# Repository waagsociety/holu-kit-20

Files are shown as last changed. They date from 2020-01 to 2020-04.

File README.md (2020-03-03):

# holu-kit-20
Hollandse Luchten sensor kit, version 2.0.

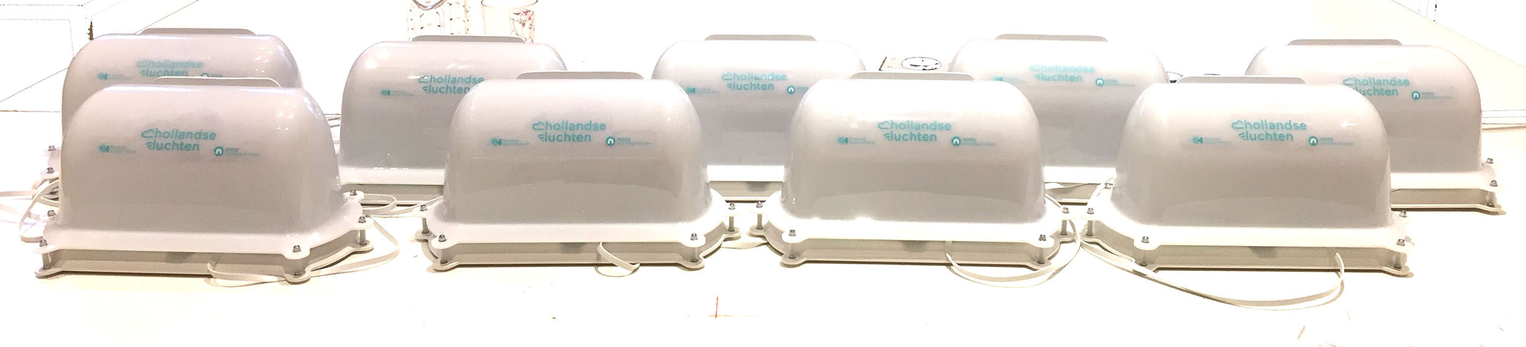
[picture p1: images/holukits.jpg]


This repo has the scope to host the source files of the HoLu kit v2.
In the repo there are:
- sketches for basic and extended HoLu kit
- 3D model of the case
- pcb files and images
- BOM

Some extra information:
- Assembling manual of the HoLu kit: https://hollandseluchten.waag.org/wp-content/uploads/sites/9/HOLU_manual_English.pdf
- Parts descriptions: https://hollandseluchten.waag.org/holu-sensorkit/
- Troubleshooting: https://hollandseluchten.waag.org/veelgestelde-vragen/

In this repo you also find the presentations related to the HoLu kit, the slides have been used during internal meetings and meet-up with the participants of the projects.

Missing:
- ~~3D model of the moulds~~: the 3D models of the moulds were designed by the company that produced the casings, the moulds are based on the original 3D models you find in this repo.
- 2D model internal acrylic plate.

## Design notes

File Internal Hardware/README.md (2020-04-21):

## Hardware - holu-kit-20

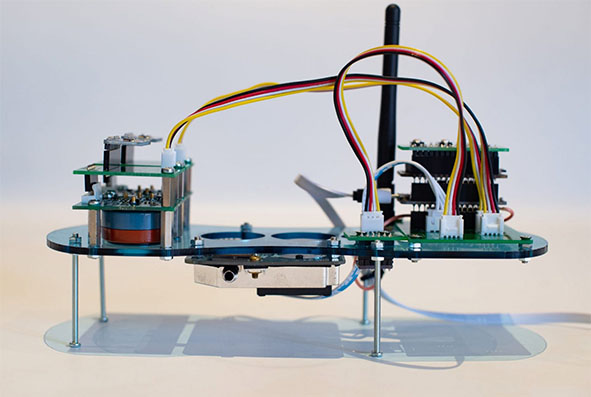
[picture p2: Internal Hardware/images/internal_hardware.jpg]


Hollandse Luchten sensor kit, version 2.0.

In this folder you find the digital files for the pcbs production used to connect the different modules of the HoLu kit v2.

The Eagle files are the design files of the printed circuit boards. The basic HoLu kit includes:
- HL_sensors_pcb_all (schematic and layout)
- HL_Interface_pcb (schematic and layout)
- hl_bme280_out_pcb (schematic and layout)

The extended HoLu kit has all the modules mentioned above and also the following ones:
- HL_gas_no2_pcb (schematic and layout)
- HL_gas_o3_pcb (schematic and layout)

The Gerber files were submitted to the out-sourced service that produced the 200 HoLu kits boards.
The boards were produced by https://jlcpcb.com/.

The images below show the boards and the components that populate them. The components specifications can be found in the BOM

## Sensors pcb top view
### Basic

| pcbs  | component locations | populated pcb |
| --- | --- | ---|
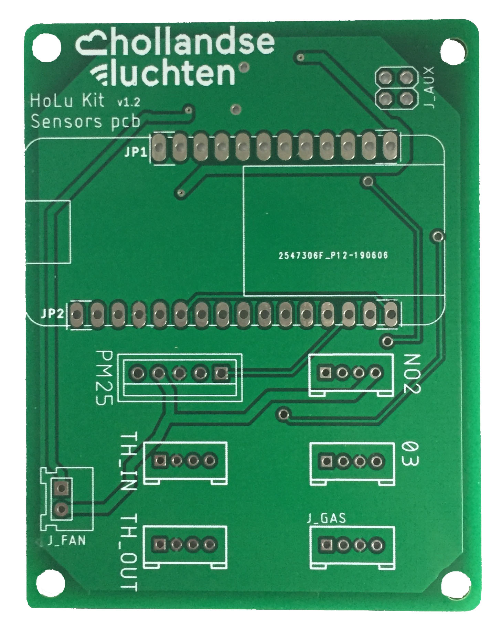
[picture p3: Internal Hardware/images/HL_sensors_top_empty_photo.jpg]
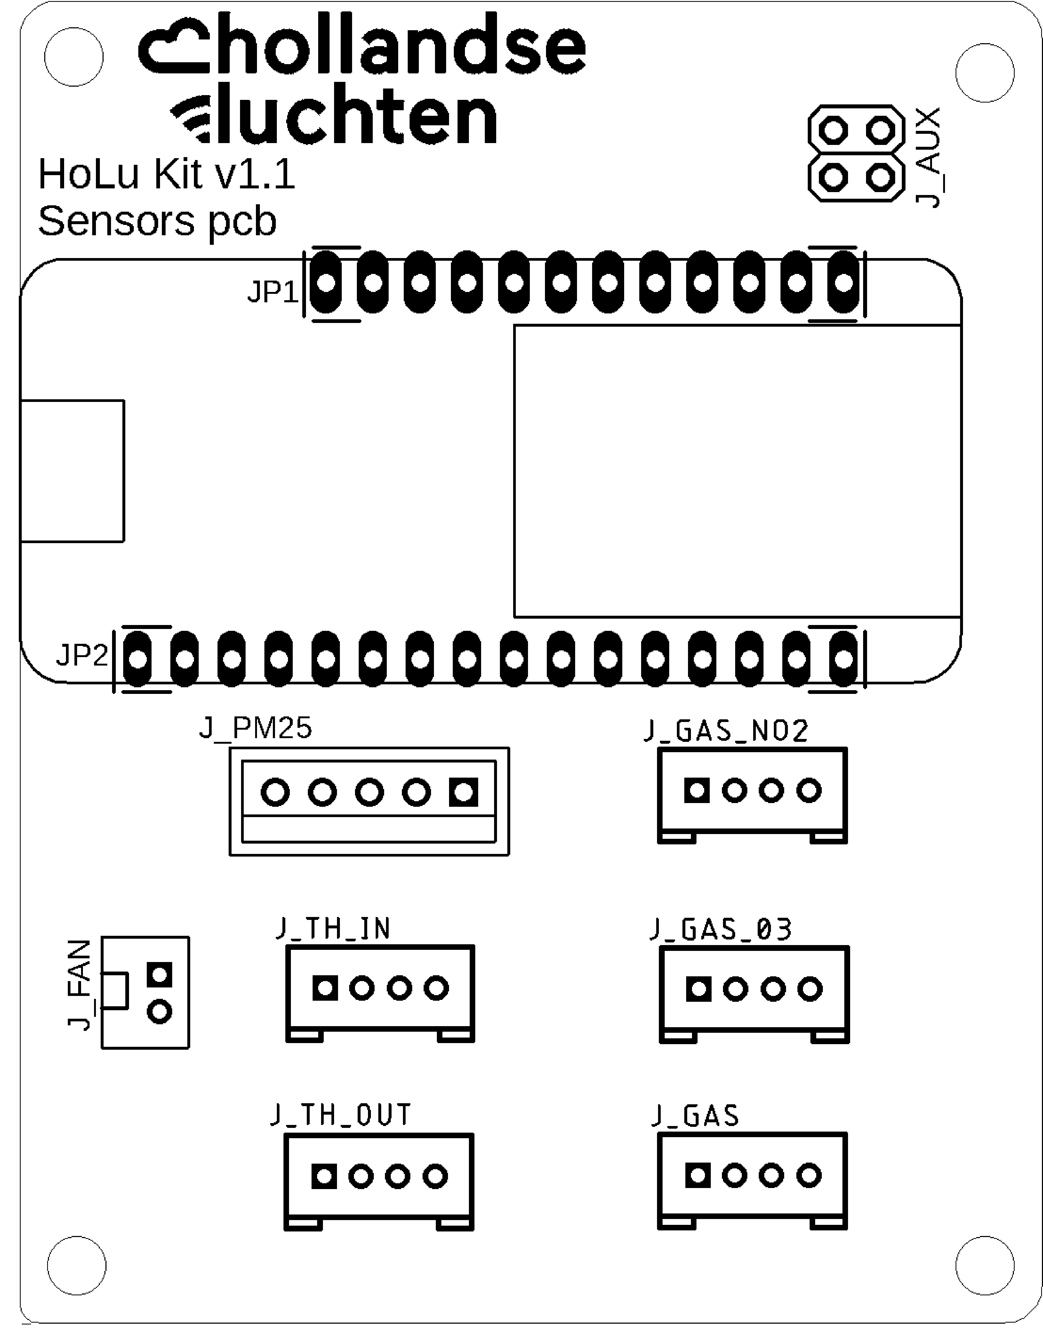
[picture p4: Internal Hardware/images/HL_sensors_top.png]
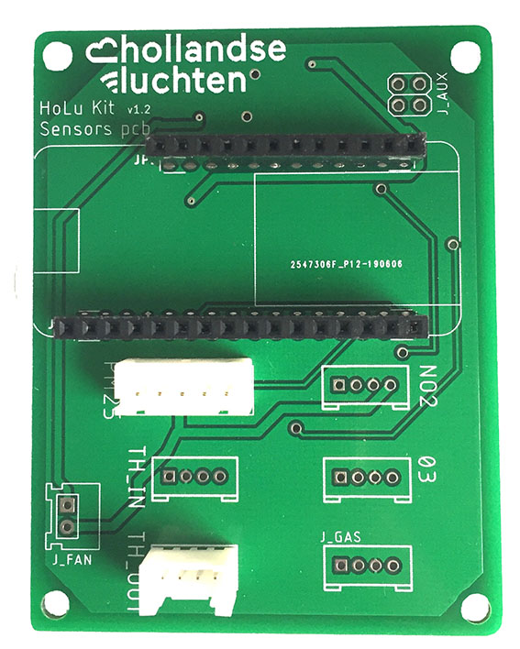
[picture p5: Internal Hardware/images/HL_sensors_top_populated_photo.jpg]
|  |  |  |

Components:
- JP1
- JP2
- J_PM25
- J_TH_IN

### Extended

| pcbs  | component locations | populated pcb |
| --- | --- | ---|
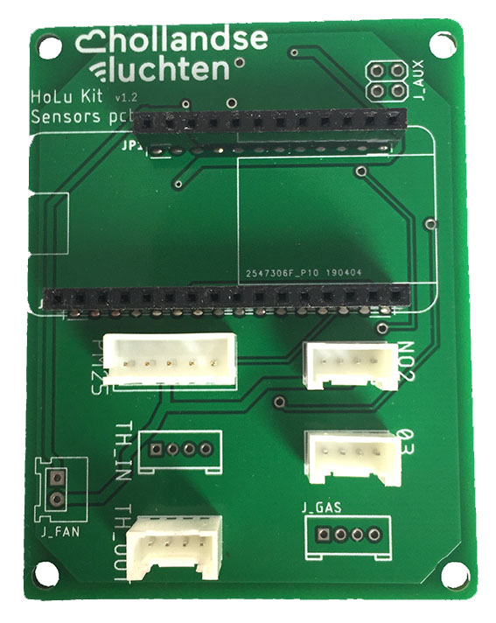
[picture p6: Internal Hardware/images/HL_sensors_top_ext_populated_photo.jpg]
|  |  |  |

Components:
- JP1
- JP2
- J_PM25
- J_TH_IN
- J_GAS_NO2
- J_GAS_O3

## Sensors pcb bottom view
### Basic

| pcbs  | component locations | populated pcb |
| --- | --- | ---|
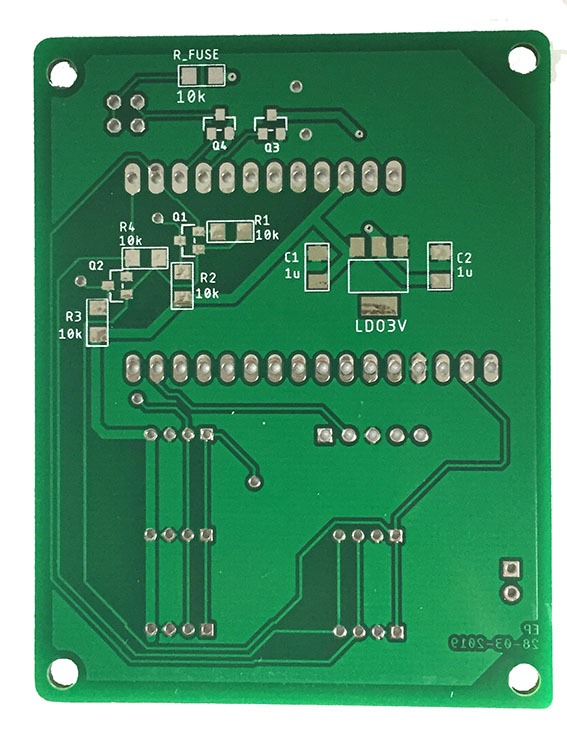
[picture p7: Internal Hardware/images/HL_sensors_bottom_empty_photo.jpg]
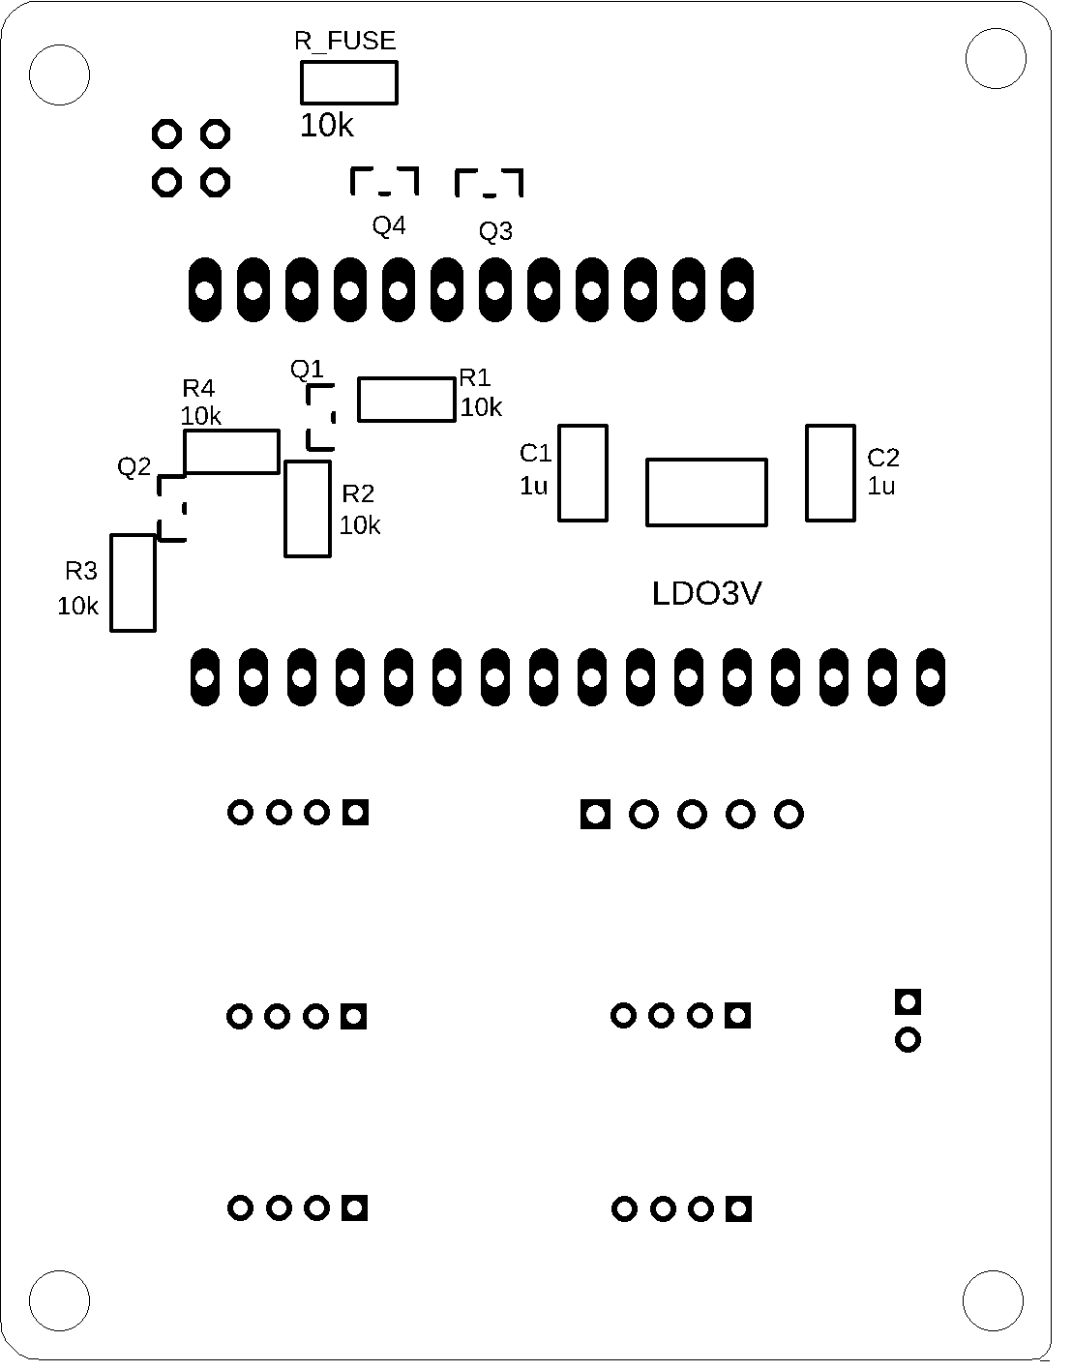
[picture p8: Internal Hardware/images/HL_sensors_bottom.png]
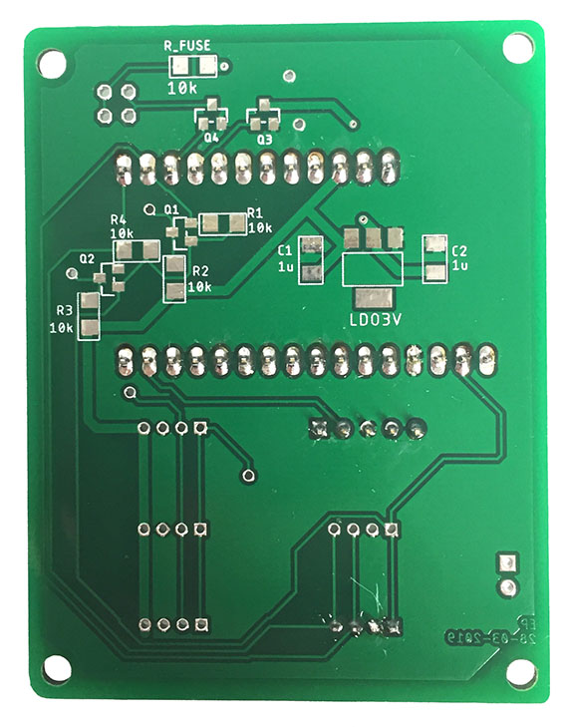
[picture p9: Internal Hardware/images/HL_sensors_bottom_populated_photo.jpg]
|  |  |  |

### Extended

| pcbs  | component locations | populated pcb |
| --- | --- | ---|
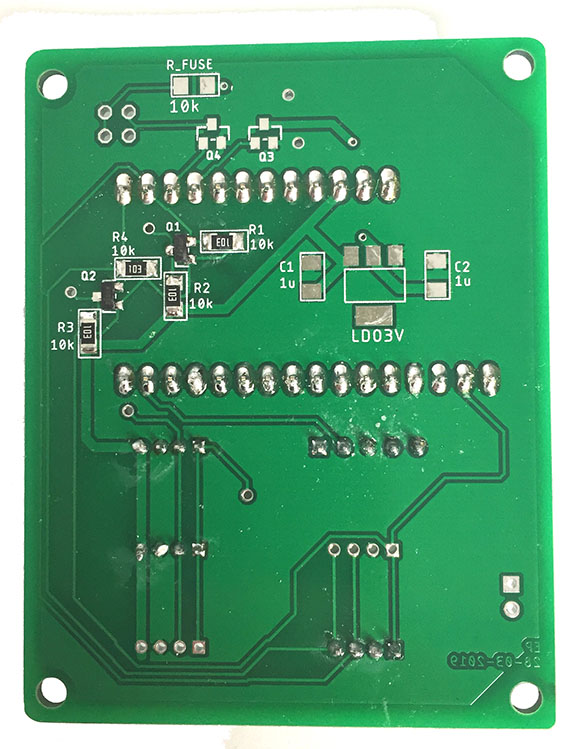
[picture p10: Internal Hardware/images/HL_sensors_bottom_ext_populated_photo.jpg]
|  |  |  |

Components:
- Q1, Q2
- R1, R2, R3, R4

### Interface pcb top view
## Basic and Extended

| pcbs  | component locations | populated pcb |
| --- | --- | ---|
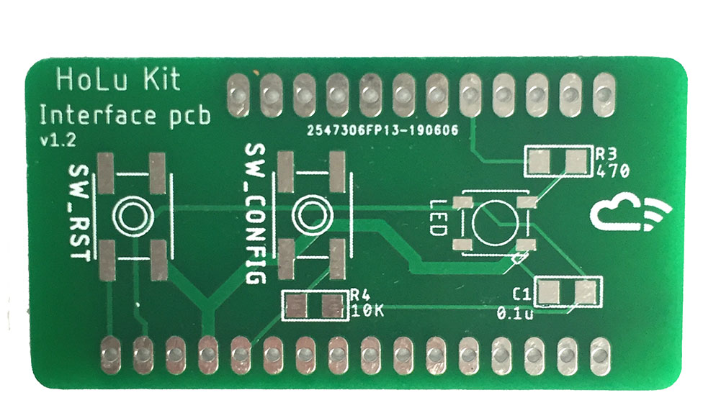
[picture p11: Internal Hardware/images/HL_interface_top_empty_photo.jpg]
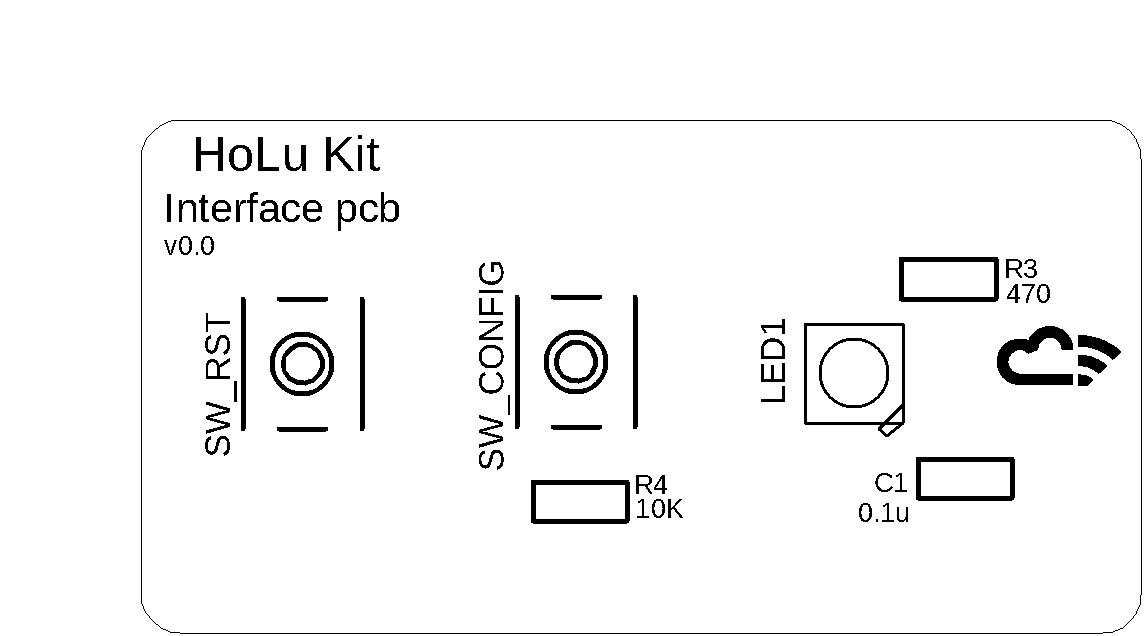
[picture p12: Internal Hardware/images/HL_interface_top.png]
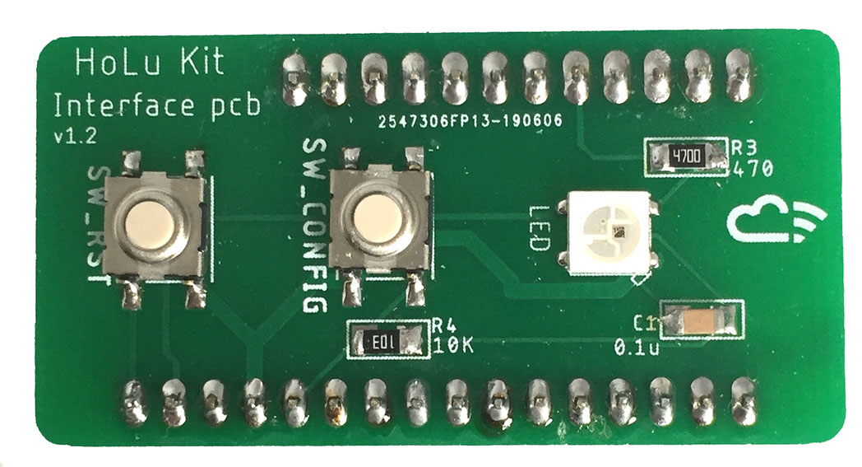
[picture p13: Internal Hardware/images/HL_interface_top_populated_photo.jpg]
|  |  |  |

Components:
- SW_RST
- SW_CONFIG
- R3, R4
- C1
- LED1

## Interface pcb bottom view
### Basic and Extended

| pcbs  | component locations | populated pcb |
| --- | --- | ---|
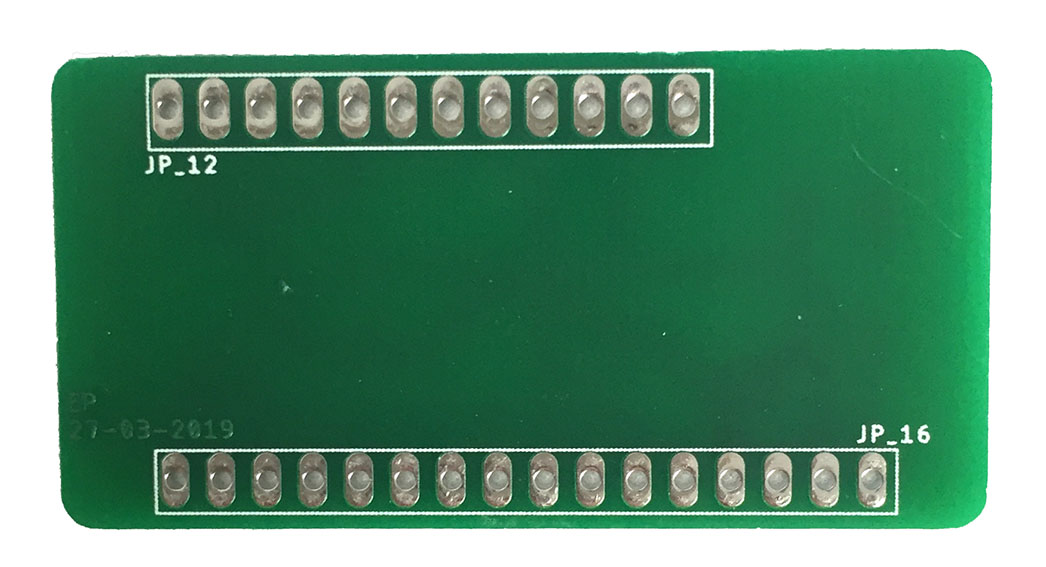
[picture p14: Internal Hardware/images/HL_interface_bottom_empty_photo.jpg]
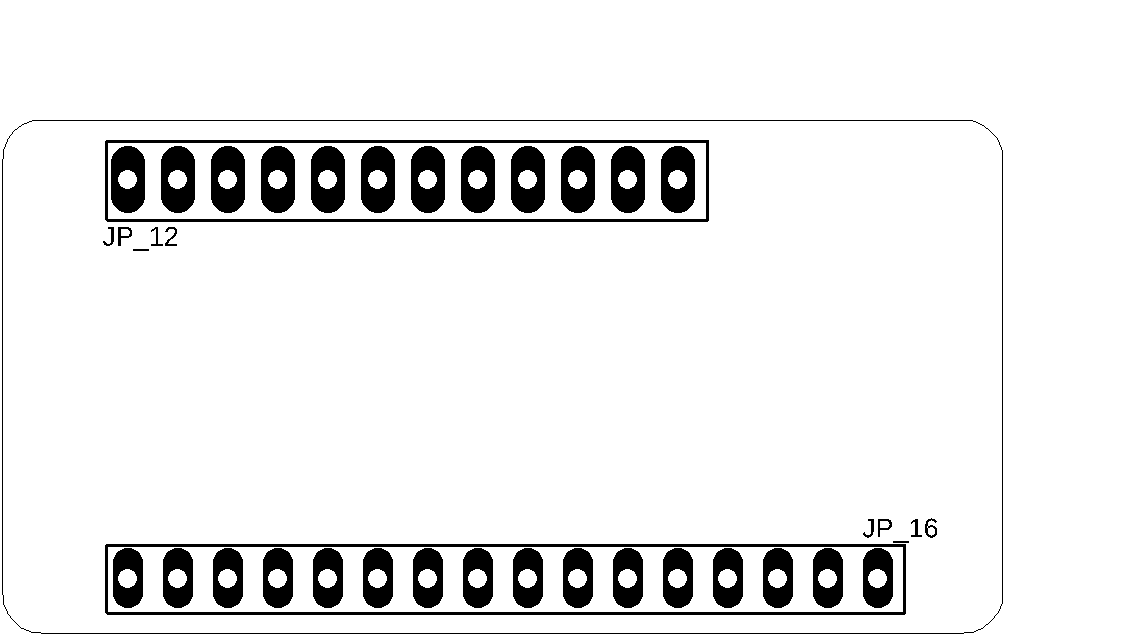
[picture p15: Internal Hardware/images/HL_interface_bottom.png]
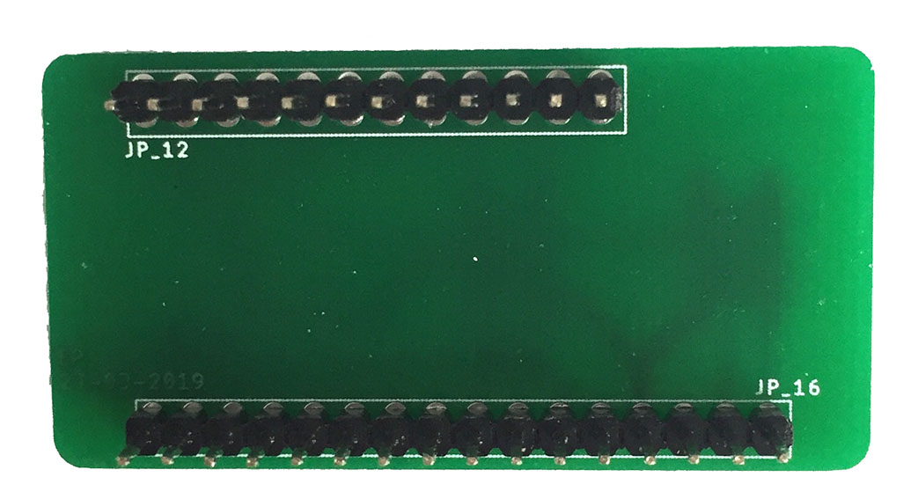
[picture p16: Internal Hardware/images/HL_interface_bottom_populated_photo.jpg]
|  |  |  |

Components:
- JP_12
- JP_16

## BME pcb top view
### Basic and Extended

| pcbs  | component locations | populated pcb |
| --- | --- | ---|
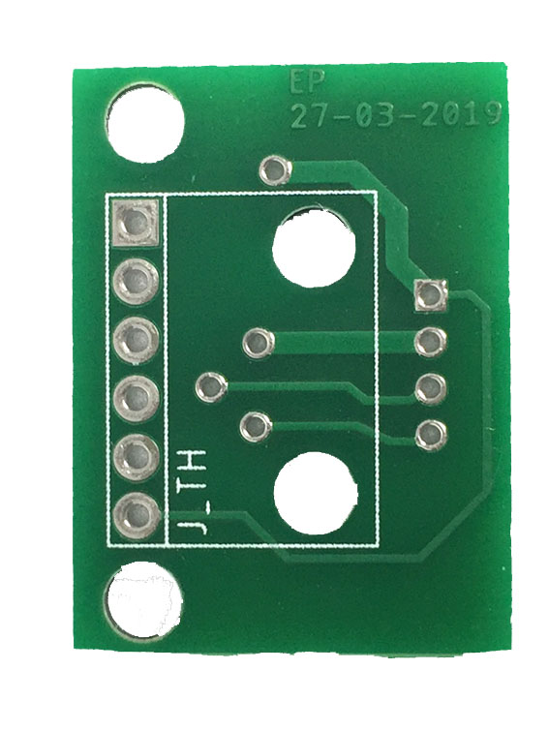
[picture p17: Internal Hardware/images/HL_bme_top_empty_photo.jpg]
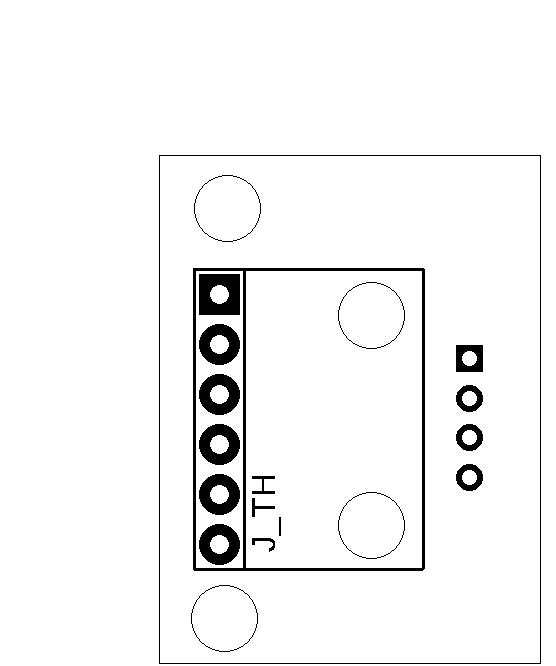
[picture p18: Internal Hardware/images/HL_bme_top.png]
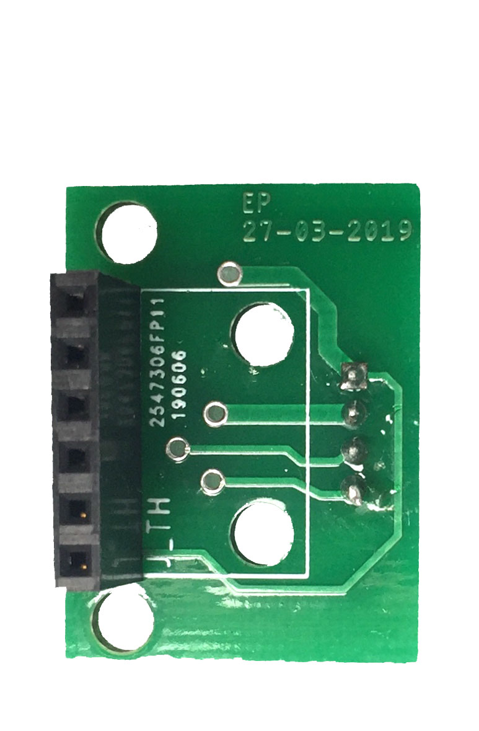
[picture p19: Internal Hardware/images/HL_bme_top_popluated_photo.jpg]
|  |  |  |

Components:
- J_TH

## BME pcb bottom view
### Basic and Extended

| pcbs  | component locations | populated pcb |
| --- | --- | ---|
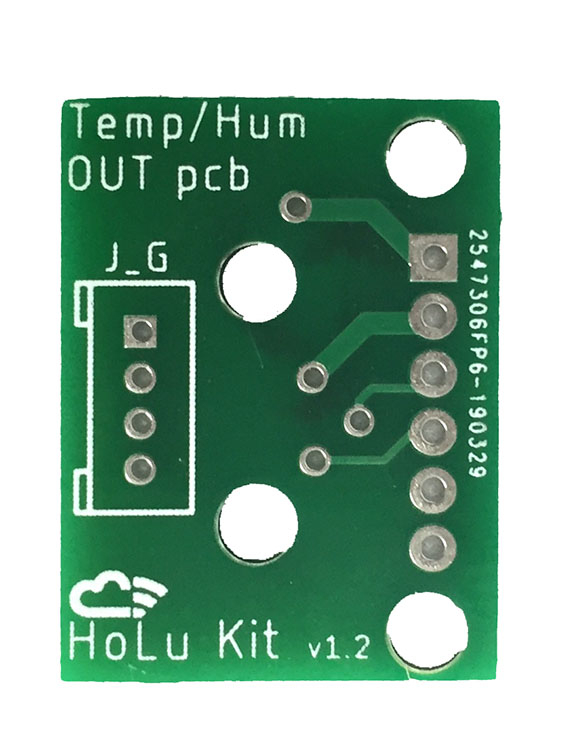
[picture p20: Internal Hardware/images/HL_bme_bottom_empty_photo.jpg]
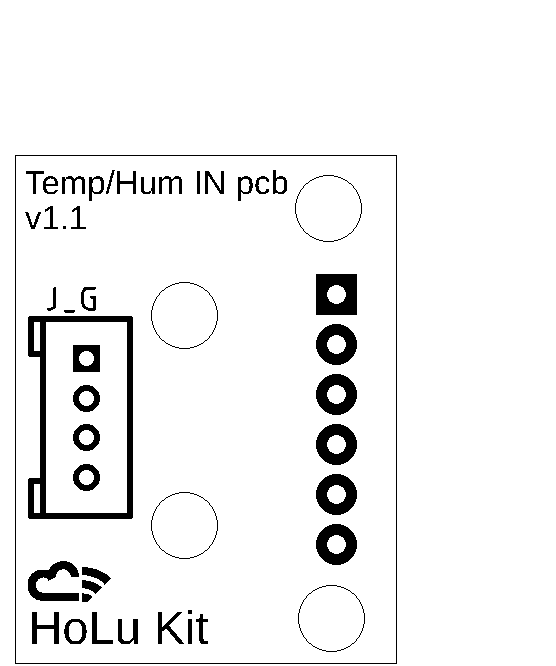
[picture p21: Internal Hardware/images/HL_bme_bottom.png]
|  |  |  |

Components:
- J_G

## GAS pcbs top view
### Extended

| pcbs  | component locations | populated pcb |
| --- | --- | ---|
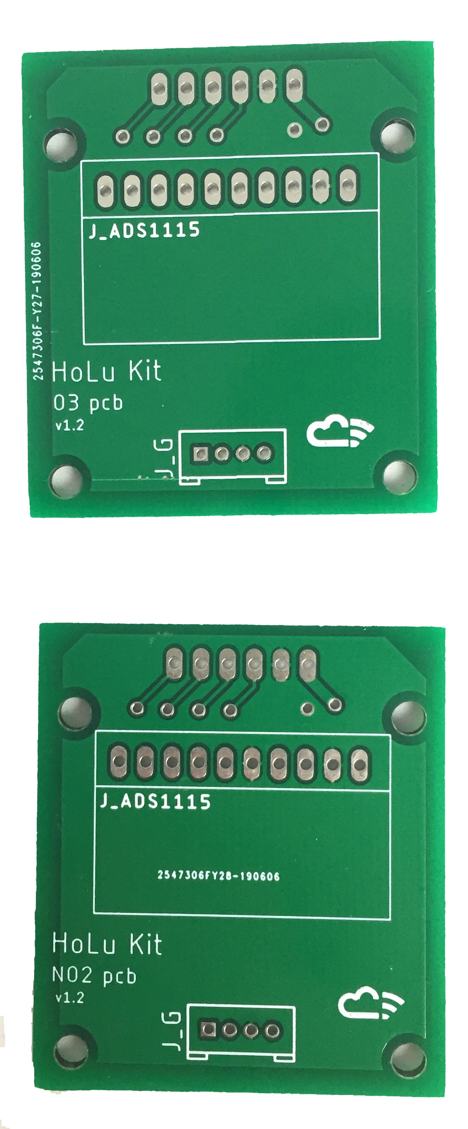
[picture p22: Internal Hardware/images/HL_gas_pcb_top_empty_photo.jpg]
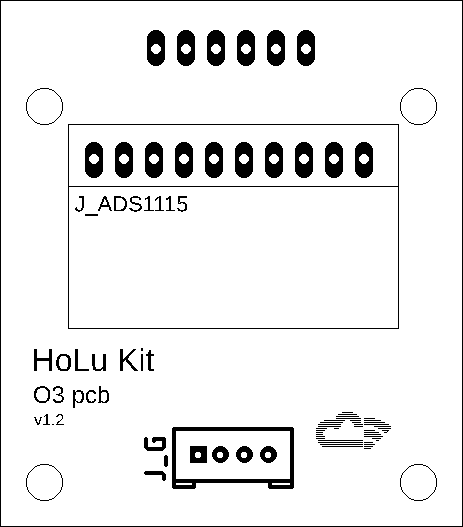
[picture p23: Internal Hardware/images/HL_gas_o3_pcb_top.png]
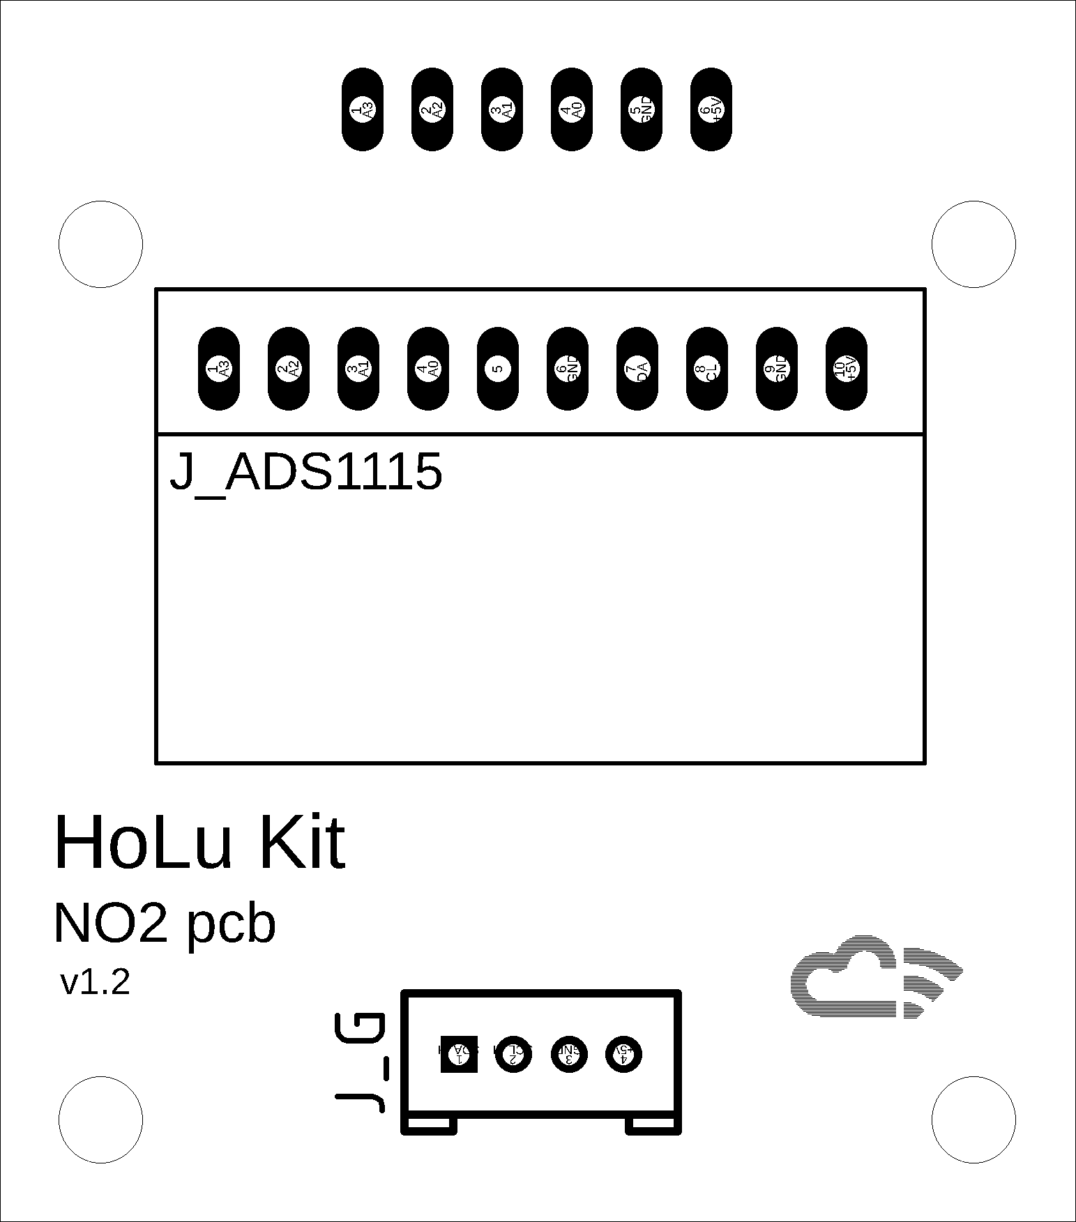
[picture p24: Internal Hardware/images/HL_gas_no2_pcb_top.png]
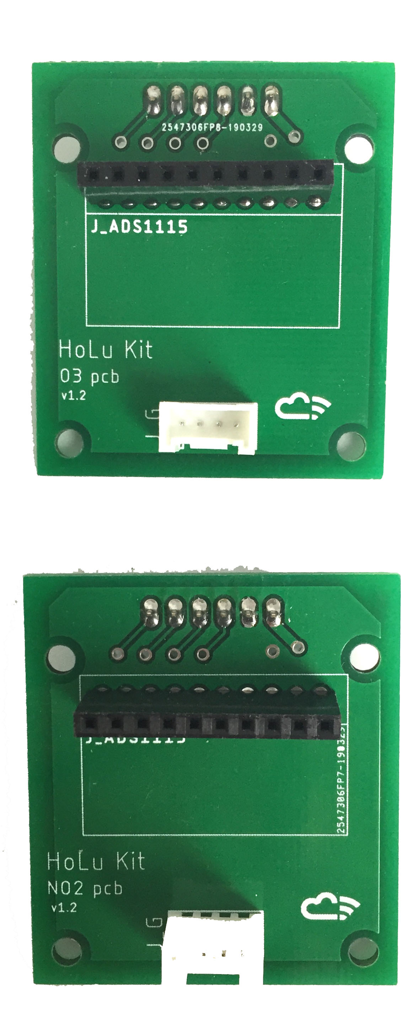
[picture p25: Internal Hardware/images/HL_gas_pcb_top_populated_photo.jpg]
|  |   |  |

Components:
- J_GAS
- J_ADS115

## GAS pcbs bottom view
### Extended

| pcbs  | component locations | populated pcb |
| --- | --- | ---|
|  |    |  |

Components:
- J_O3
- C1, C2

## EXTRA
### Internal plate
The HoLu kit uses an acrylic plate to hold the sensors and the electronic parts in place. The plates were cut in the Fablab at De Waag.


### Feather M0 with RFM95 LORA Radio


It is important to buy the Feather M0 Lora with headers because the connectors that are usually provided attached to the board are too short for this application.
It is necessary to use the long staking headers, see BOM. It is also necessary to solder the coaxial connector for the antenna to the board.
You can find the instruction at this link: https://learn.adafruit.com/adafruit-feather-m0-radio-with-rfm69-packet-radio/antenna-options.

### Adalogger Feather


On this module it is necessary to solder the female connector and insert the battery and the SD-card, https://learn.adafruit.com/adafruit-adalogger-featherwing.

### Temperature and Humidity Sensor
The sesnor selected to measure temperature and humidity is the sensor BME280 from Bosh: https://www.bosch-sensortec.com/products/environmental-sensors/humidity-sensors-bme280/.

Due to tools limitation, the sensor has been deployed on a low cost breakout board:


**NOTE**: During the on the field deployment of the HoLu kits, we observed that temperature sensor BME280 module is too fragile for such application and after a while many it tends to break. The Extended HoLu kit requires the temp/hum sensor for the calibration of the gas sensors so we adopted a different breakout board with the same sensor, the module provided by Adafruit, https://www.adafruit.com/product/2652.


To better protect the module inside the HoLu kit enclosure, it has been located in a more central place inside the casing.



If you are interested on the connection between the extra module, please open an issue in the issue section.

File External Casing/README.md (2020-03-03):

In this section of the repo you find the 3D models, .STEP files, of the HoLu kit casing. It is composed by two parts, the top and the bottom.
The first prototype was designed and made in the Fablab at De Waag.

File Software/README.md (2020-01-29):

# Software
In this folder you find the code used in the basic and extended HoLu kit version 2.

The sketches are written for the Adafruit M0 lora board.<br>
The code for the basic kit is called: HL_main_basic.<br>
The code for the basic kit is called: HL_main_extended.

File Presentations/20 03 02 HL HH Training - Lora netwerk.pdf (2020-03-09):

Hollandse Luchten

Lora netwerk en data infrastructuur

Denis Costa, projectmanager

## Agenda

- Wat is Lora netwerk?
- Waarom Lora netwerk?
- Lora en Hollandse Luchten

## Netwerk

criteria/type netwerk | Accessible for users & dataplatform | Open source | Price | Scalability (200 sensors)
4G | yes | no | expensive | no
Wifi | no | no | free | yes
Lora | yes | yes | free | yes

## Long-RAnge Wide Area Network


https://www.thethingsnetwork.org/


## Overzicht Gateways in de IJmond


https://ttnmapper.org/

## Hollandse Luchten technische infrastructuur

hardware | netwerk- infrastructuur

datainfrastructuur

visualisatie

HoLu-Sensorkits

LoRa Gateways TTN | TTN server
| MQTT broker

WAAG server

RIVM server
kalibratie/correctie

MQTT subscription

MQTT subscription

gekalibreerde/
gecorrigeerde data

kaart op website
Hollandse Luchten
ruwe data

GGD server

http POST

TEOM +
Station Bosweg

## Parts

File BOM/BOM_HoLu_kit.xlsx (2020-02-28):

 | Name | Description | Amount/kit | Supplier | Order code | Minimum Amount | Cost Minimum amount (€) | Cost per Kit (euro) | Link
BASIC |  |  |  |  |  |  | 456.359 | 123.4758
Off the shelf / sensors
 | Feather M0 Lora | FEATHER M0 WITH RFM95 LORA RADIO, Adafruit | 1 | Antratek OR MUISER | P2821 | 1.00 | 39.87 | 39.87 | https://www.antratek.nl/feather-m0-with-rfm95
 | Antenna adapter | SMA naar uFL/u.FL/IPX/IPEX RF kabel | 1 | opencircuit |  | 1 | 5.95 | 5.95 | https://opencircuit.nl/Product/13952/SMA-naar-uFLu.FLIPXIPEX-RF-kabel
 | Atenna connector | RF / Coaxial Connector, U.FL Coaxial, Straight Jack, Solder, 50 ohm, Phosphor Bronze | 1 | farnell |  | 10 | 9.46 | 0.946 | https://nl.farnell.com/hirose-hrs/u-fl-r-smt-01/rf-coaxial-u-fl-straight-jack/dp/3908021
 | Antenna | 868 MHz antenne SMA knik | 1 | Ideetron |  | 1.00 | 5.39 | 5.39 | https://webshop.ideetron.nl/Webwinkel-Product-24476807/868-MHz-antenne-SMA-knik.html
 | Adalogger Feather | Adalogger FeatherWing - RTC + SD Add-on For All Feather Boards | 1 | Open Circuit | ADA-2922 | 1.00 | 7.82 | 7.82 | https://nl.mouser.com/ProductDetail/Adafruit/2922 | https://www.reichelt.nl/experimenteerbord-adalogger-featherwing-rtc-sd-extensie-debo-feather-rtc-p235464.html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 | https://www.hobbyelectronica.nl/product/adalogger-featherwing-rtc-sd/ | https://www.kiwi-electronics.nl/adalogger-featherwing-rtc-sd-add-on | https://www.elektor.nl/adalogger-featherwing-rtc-sd-add-on
 | Feather Stacking Headers | 12-pin and 16-pin female headers | 2 | Open Circuit | ADA-2830 | 1.00 | 1.90 | 3.8 | https://opencircuit.nl/Product/12816/Feather-Stacking-Headers-12-pin-and-16-pin-female-headers
 | BME280 breakout board | BMP280 I2C or SPI Barometric Pressure / Temperature / Altitude Sensor | 1 | tinytronics | 1511 | 1.00 | 4.50 | 4.5 | https://www.tinytronics.nl/shop/nl/sensoren/temperatuur-lucht-vochtigheid/bme280-digitale-barometer-druk-en-vochtigheid-sensor-module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
 | SDS011 | PM2.5 sensor | 1 | tiny tronics | 1548 | 1.00 | 25.00 | 25 | https://www.tinytronics.nl/shop/nl/sensoren/temperatuur-lucht-vochtigheid/nova-sds011-hoge-precisie-laser-stofsensor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
Interface pcb
 | JP3 | Board-To-Board Connector, Vertical, 2.54 mm, 12 Contacts, Through Hole, 1 Rows | 1 |  |  |  |  |  | use from other components, no need to buy it
 | JP1 | Board-To-Board Connector, 2.54 mm, 16 Contacts, Receptacle, WR-PHD Series, Through Hole, 1 Rows | 1 |  |  |  |  |  | use from other components, no need to buy it
 | SW_RST, SW_CONFIG | Tactile Switch, B3SN Series, Top Actuated, SMD, Round Button, 160 gf, 50mA at 24VDC | 2 | Farnell | 2076274 | 5 | 3.75 | 1.5 | https://nl.farnell.com/omron-electronic-components/b3sn-3112p/switch-6x6x3-1mm-sealed-1-57n/dp/2076274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
 | R1 | RC1206JR-0710KL - SMD Chip Resistor, 1206 [3216 Metric], 10 kohm, RC Series, 200 V, Thick Film, 250 mW | 1 | farnell | 9240640 | 10.00 | 0.61 | 0.061 | https://nl.farnell.com/yageo/rc1206jr-0710kl/res-10k-5-0-25w-1206-thick-film/dp/9240640
 | R2 | RC1206FR-07470RL - SMD Chip Resistor, 1206 [3216 Metric], 470 ohm, RC Series, 200 V, Thick Film, 250 mW | 1 | farnell | 9240926 | 10.00 | 0.70 | 0.0699 | https://nl.farnell.com/yageo/rc1206fr-07470rl/res-470r-1-0-25w-1206-thick-film/dp/9240926
 | C1 | C1206C104KARACTU - SMD Multilayer Ceramic Capacitor, Tip & Ring, 0.1 µF, 250 V, 1206 [3216 Metric], ± 10%, X7R | 1 | farnell | 2429364 | 10.00 | 3.31 | 0.331 | https://nl.farnell.com/kemet/c1206c104karactu/cap-0-1-f-250v-10-x7r-1206/dp/2429364?st=C1206C104KARACTU
 | LED1 | WS2812B RGB Led, Neopixel, package 5050 | 1 | Opencircuit | 10707 | 10.00 | 1.95 | 0.195 | https://opencircuit.nl/Product/10707/WS2812B-RGB-led-10-stuks
Temp/Hum pcb (2 boards)
 | J3 | 61300611821 - Board-To-Board Connector, 2.54 mm, 6 Contacts, Receptacle, WR-PHD Series, Through Hole, 1 Rows | 1 | farnell | 1109731 | 10.00 | 2.04 | 0.204 | https://nl.farnell.com/wurth-elektronik/61300611821/connector-rcpt-6pos-1row-2-54mm/dp/2827893
 | J1 | Grove - Universal 4-Pin Connector | 1 | Kiwi electronics | SS-110990030 | 10.00 | 1.31 | 0.131 | https://nl.mouser.com/ProductDetail/Seeed-Studio/110990030
Sensor pcb basic
 | JP2 | Board-To-Board Connector, 2.54 mm, 16 Contacts, Receptacle, WR-PHD Series, Through Hole, 1 Rows | 1 | Farnell | 2827905 | 10.00 | 5.64 | 0.564 | https://nl.farnell.com/wurth-elektronik/61301611821/connector-rcpt-16pos-1row-2-54mm/dp/2827905
 | JP1 | Board-To-Board Connector, 2.54 mm, 12 Contacts, Receptacle, WR-PHD Series, Through Hole, 1 Rows | 1 | Farnell | 2827901 | 10.00 | 4.90 | 0.49 | https://nl.farnell.com/wurth-elektronik/61301211821/connector-rcpt-12pos-1row-2-54mm/dp/2827901
 | J-TH (x2) | Grove - Universal 4-Pin Connector | 2 | Kiwi electronics | SS-110990030 | 10.00 | 1.31 | 0.262 | https://www.kiwi-electronics.nl/grove-universal-4-pin-connector-10-pack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
 | 05-JST-B5B | Dust - Wire-To-Board Connector, Vertical, 2.5 mm, 5 Contacts, Header, XH Series, Through Hole, 1 Rows | 1 | farnell | 1516281 | 100.00 | 14.60 | 0.146 | https://nl.farnell.com/jst-japan-solderless-terminals/b5b-xh-a-lf-sn/header-tht-vertical-2-5mm-5way/dp/1516281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
Extra
 | grove cables | Grove - Universal 4 Pin Unbuckled 20cm Cable. | 1 | mouser.nl |  | 5.00 | 2.53 | 0.506 | https://nl.mouser.com/ProductDetail/Seeed-Studio/110990031
 | usb cable | Micro USB kabel - 1.8m | 1 | tinytronics |  | 1.00 | 2.50 | 2.5 | https://www.tinytronics.nl/shop/en/cables/usb/micro-usb-cable-1.8m
 | usb adapter/charger | USB wall adapter | 1 | tinytronics |  | 1 | 6.5 | 6.5 | https://www.tinytronics.nl/shop/en/power-supplies/5v/goobay-44951-dual-usb-power-supply-5v-2.4a-black
 | sdscard | opencircuit | 1 | open circuit |  | 1 | 6.95 | 6.95 | https://opencircuit.nl/Product/11234/8GB-Micro-SD-geheugenkaart
 | battery for RTC | CR1220 3V lithium metal coin cell battery | 1 | allekabels |  | 5 | 1.99 | 0.398 | https://www.allekabels.nl/knoopcel-batterij/1067/1296899/knoopcel-batterij.html
 | metal rings |  | 2
 | rip-tie |  | 1 | local shop |  | 100 | 4 | 0.08
 | metal plate with screws |  | 1
Fasteners (internal)
 | M3 nut | Jeveca | 9 | Jeveka |  | 1000 | 25.9 | 0.2331 | https://www.jeveka.com/nl/catalog/metrische-zeskant-en-vierkantmoeren/lage-zeskantmoeren/lage-zeskantmoeren-4390006z/4390006z0030000/staal-klasse-4-4.6-4.8/m-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
 | borgringen | essentracomponents | 9 | Jeveka |  | 1000 | 24 | 0.216 | https://www.essentracomponents.com/nl-nl/p/borgringen/015103000203
 | M3x12 bolt | Jeveca | 9 | Jeveka |  | 2000 | 53.2 | 0.2394 | https://www.jeveka.com/nl/catalog/metrische-metaalschroeven-met-torx-of-kruisgleuf/bolcilinderschroeven-met-kruisgleuf-staal/bolcilinderschr.kr.gl.h-7985004z/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
Fasteners to acrilic/bottom
 | M3x50 bolt | Jeveca | 4 | Jeveka |  | 200 | 38.6 | 0.772 | https://www.jeveka.com/nl/catalog/metrische-metaalschroeven-met-torx-of-kruisgleuf/bolcilinderschroeven-met-kruisgleuf-staal/bolcilinderschr.kr.gl.h-7985004z/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
 | M3 nut | Jeveca | 8 | Jeveka |  | 1000 | 25.9 | 0.2072 | https://www.jeveka.com/nl/catalog/metrische-zeskant-en-vierkantmoeren/lage-zeskantmoeren/lage-zeskantmoeren-4390006z/4390006z0030000/staal-klasse-4-4.6-4.8/m-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
 | M3 washer | Jeveca | 16 | Jeveka |  | 5000 | 15 | 0.048 | https://www.jeveka.com/nl/catalog/sluitringen-en-borgplaten/sluitringen-vlak-normaal-staal-zn-tzn-zndikgepass-zinklamel/sluitringen-normaal-voor-6-kt-125a001z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
 | M3x16mm plastic spacer | Mouser | 8 | Mouser |  | 1 | 0.49 | 3.92 | https://nl.mouser.com/ProductDetail/855-R30-6701694
Fasteners top/bottom
 | M3x30 bolt | Jeveka | 6 | Jeveka |  | 1000 | 50 | 0.3 | https://www.jeveka.com/nl/catalog/metrische-metaalschroeven-met-torx-of-kruisgleuf/bolcilinderschroeven-met-kruisgleuf-staal/bolcilinderschr.kr.gl.h-7985004z/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
 | M3x16mm plastic spacer | Mouser | 6 | Mouser |  | 1 | 0.49 | 2.94 | https://nl.mouser.com/ProductDetail/855-R30-6701694
 | M3 washer | Jeveka | 24 | Jeveka |  | 5000 | 15 | 0.072 | https://www.jeveka.com/nl/catalog/sluitringen-en-borgplaten/sluitringen-vlak-normaal-staal-zn-tzn-zndikgepass-zinklamel/sluitringen-normaal-voor-6-kt-125a001z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
 | M3 nut | Jeveka | 6 | Jeveka |  | 1000 | 25.9 | 0.1554 | https://www.jeveka.com/nl/catalog/metrische-zeskant-en-vierkantmoeren/lage-zeskantmoeren/lage-zeskantmoeren-4390006z/4390006z0030000/staal-klasse-4-4.6-4.8/m-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
 | M3 self-locking Nut | Javeka | 6 | Jeveka |  | 500 | 17.4 | 0.2088 | https://www.jeveka.com/nl/catalog/metrische-moeren-zelfborgend-durlok-en-andere-vormen/zelfborgende-moeren-staal-met-kunststof-ring/zelfb.zesk.moeren-kunstst.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
Extra not counted
 | acrilic plate | 3mm, 20x30cm | 1 | kunststofplatenshop |  |  |  |  |  | b. Solderen elektronische boards 1 uur per stuk * 10 sensoren = 10 uur |  |  |  | 10
EXTRA COMPONENTS FOR EXTENDED |  |  |  |  |  |  | 115.785 | 112.8336
Off the shelf / sensors
 | NO2-B43F | NO2 sensor Compact, 4-electrode, low ppb | 1 | alphasense |  |  |  |  | http://www.alphasense.com/
 | OX-B431 | O3 Compact, 4-electrode, low ppb | 1 | alphasense |  |  |  |  | http://www.alphasense.com/
 | ISB Individual Sensor Board | ISB for B series 4-electrode sensors | 2 | alphasense |  |  |  |  | http://www.alphasense.com/
 | ADS1115 | ADC converter | 2 | opencircuit |  | 1.00 | 15.25 | 30.5 | https://opencircuit.nl/Product/14001/ADS1115-16-Bit-ADC-4-kanaals-met-Programmeerbare-gain-versterker
Sensor pcb basic
 | J-TH (x2) | Grove - Universal 4-Pin Connector | 2 | Kiwi electronics | SS-110990030 | 10.00 | 1.31 | 0.262 | https://www.kiwi-electronics.nl/grove-universal-4-pin-connector-10-pack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
 | Q1 Q2 | MOSFET Transistor, N Channel, 1.7 A, 30 V, 0.065 ohm, 10 V, 1.6 V | 2 | farnell | 9845429 | 5.00 | 1.68 | 0.67 | https://nl.farnell.com/on-semiconductor/nds355an/mosfet-n-sot-23/dp/9845429?st=NDS355AN
 | R1 R2 R3 R4 | RC1206JR-0710KL - SMD Chip Resistor, 1206 [3216 Metric], 10 kohm, RC Series, 200 V, Thick Film, 250 mW | 4 | farnell | 9240640 | 10.00 | 0.61 | 0.244 | https://nl.farnell.com/yageo/rc1206jr-0710kl/res-10k-5-0-25w-1206-thick-film/dp/9240640
Extra
 | grove cables | Grove - Universal 4 Pin Unbuckled 20cm Cable. | 2 | mouser |  | 5.00 | 2.53 | 1.012 | https://nl.mouser.com/ProductDetail/Seeed-Studio/110990031
Gas pcb NO2
 | grove cables | Grove - Universal 4 Pin Unbuckled 20cm Cable. | 1 | mouser |  | 5.00 | 2.53 | 0.506 | https://nl.mouser.com/ProductDetail/Seeed-Studio/110990031
 | JP1 | 2212S-10SG-85 - Board-To-Board Connector, 2.54 mm, 10 Contacts, Receptacle, 2212S Series, Through Hole, 1 Rows | 1 | farnell |  | 5 | 1.125 | 0.225 | https://nl.farnell.com/multicomp/2212s-10sg-85/socket-pcb-1-row-10way/dp/1593464
 | C1 | C1206C104KARACTU - SMD Multilayer Ceramic Capacitor, Tip & Ring, 0.1 µF, 250 V, 1206 [3216 Metric], ± 10%, X7R | 1 | farnell |  | 5 | 1.655 | 0.331 | https://nl.farnell.com/kemet/c1206c104karactu/cap-0-1-f-250v-10-x7r-1206/dp/2429364?st=C1206C104KARACTU
 | C2 | 12065C105JAT2A - SMD Multilayer Ceramic Capacitor, 1 µF, 50 V, 1206 [3216 Metric], ± 5%, X7R, AVX 1206 MLCC | 1 | farnell |  | 5 | 3.01 | 0.602 | https://nl.farnell.com/avx/12065c105jat2a/cap-1-f-50v-5-x7r-1206/dp/1740706
Fasteners (internal)
 | Offset pillar m3x16 m-f |  | 8 | farnell |  | 1 | 7.93 | 63.44 | https://nl.farnell.com/webapp/wcs/stores/servlet/ProductDisplay?scope=partnumberlookahead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
 | Offset pillar m3x13 m-f |  | 4 | farnell |  | 1 | 3.66 | 14.64 | https://nl.farnell.com/harwin/r30-3001302/standoff-hex-brass-13mm-m3/dp/2395872
 | M3x6 bolt |  | 8 | Jeveka |  | 2000 | 48.6 | 0.1944 | https://www.jeveka.com/nl/catalog/metrische-metaalschroeven-met-torx-of-kruisgleuf/bolcilinderschroeven-met-kruisgleuf-staal/bolcilinderschr.kr.gl.h-7985004z/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
 | M3 nut |  | 8 | Jeveka |  | 1000 | 25.9 | 0.2072 | https://www.jeveka.com/nl/catalog/metrische-zeskant-en-vierkantmoeren/lage-zeskantmoeren/lage-zeskantmoeren-4390006z/4390006z0030000/staal-klasse-4-4.6-4.8/m-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

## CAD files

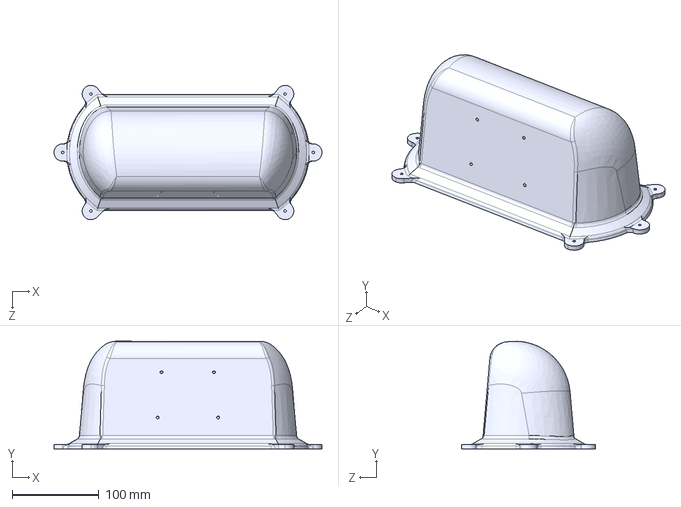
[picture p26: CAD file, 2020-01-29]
External Casing/HoLu kit Top case.STEP
308.4 x 123.7 x 154.6 mm

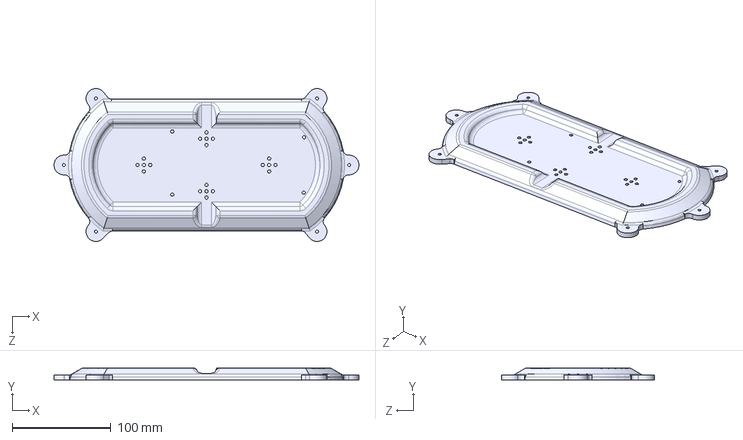
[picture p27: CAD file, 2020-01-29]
External Casing/HoLu kit Bottom case.STEP
308.4 x 12.5 x 154.6 mm

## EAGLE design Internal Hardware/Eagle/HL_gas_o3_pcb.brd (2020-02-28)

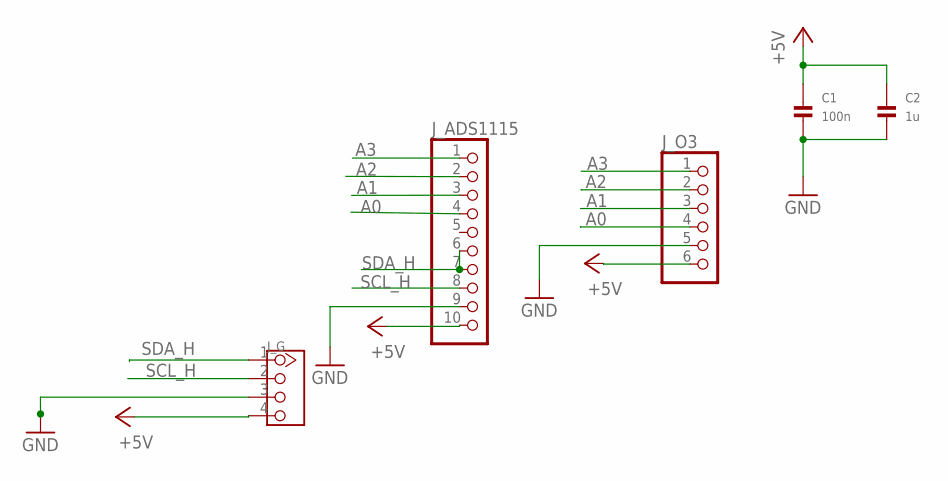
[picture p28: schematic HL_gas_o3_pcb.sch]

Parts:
C1: 100n; 1206
C2: 1u; 1206
J_ADS1115: HEADER-1X10; 1X10_OVAL
J_G: TWIG-4P-2.0-2.0; 4P-2.0
J_O3: HEADER-1X6; 1X06_OVAL

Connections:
+5V: C1.1, C2.1, J_ADS1115.10, J_G.4, J_O3.6
A0: J_ADS1115.4, J_O3.4
A1: J_ADS1115.3, J_O3.3
A2: J_ADS1115.2, J_O3.2
A3: J_ADS1115.1, J_O3.1
GND: C1.2, C2.2, J_ADS1115.9, J_G.3, J_O3.5
SCL_H: J_ADS1115.8, J_G.2
SDA_H: J_ADS1115.6, J_ADS1115.7, J_G.1

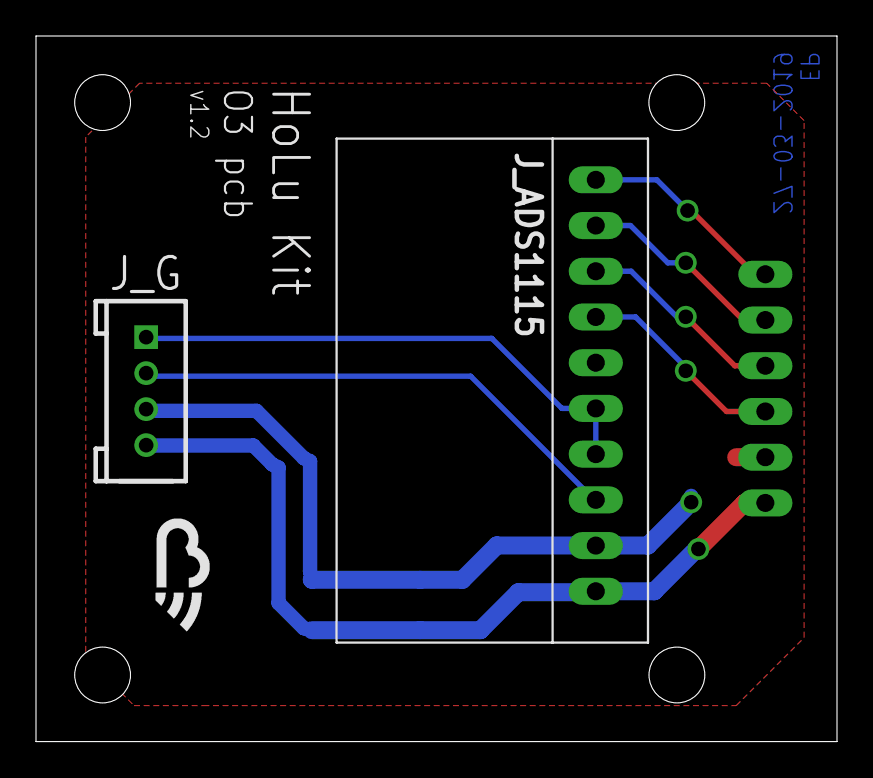
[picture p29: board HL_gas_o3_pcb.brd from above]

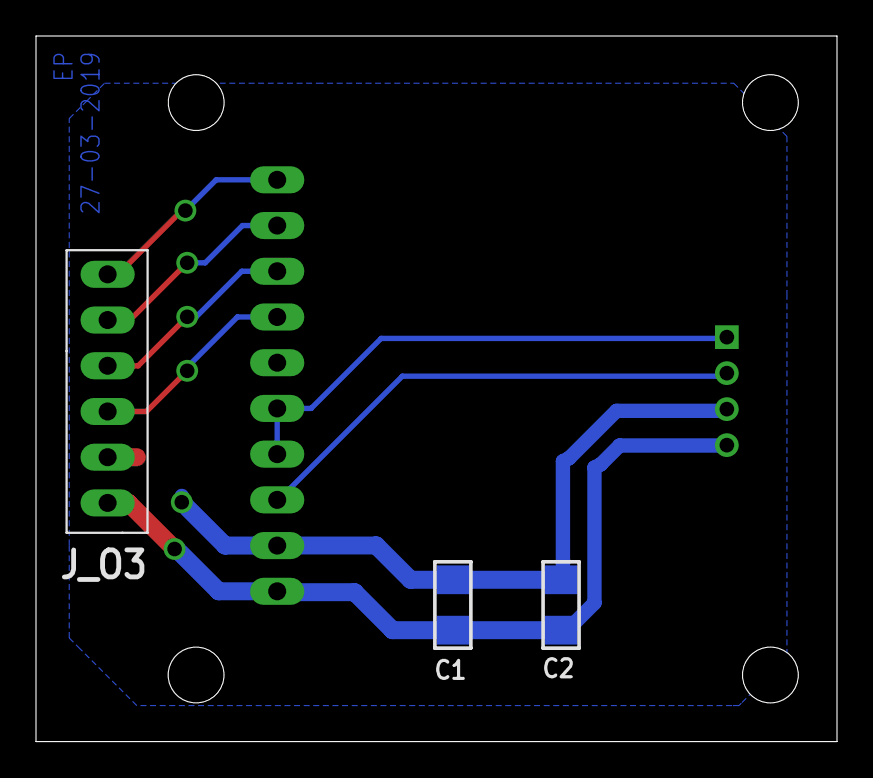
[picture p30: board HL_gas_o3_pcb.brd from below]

Board: 2 copper layers, 44.5 x 39.2 mm, 5 parts (2 on the bottom side), 8 nets.

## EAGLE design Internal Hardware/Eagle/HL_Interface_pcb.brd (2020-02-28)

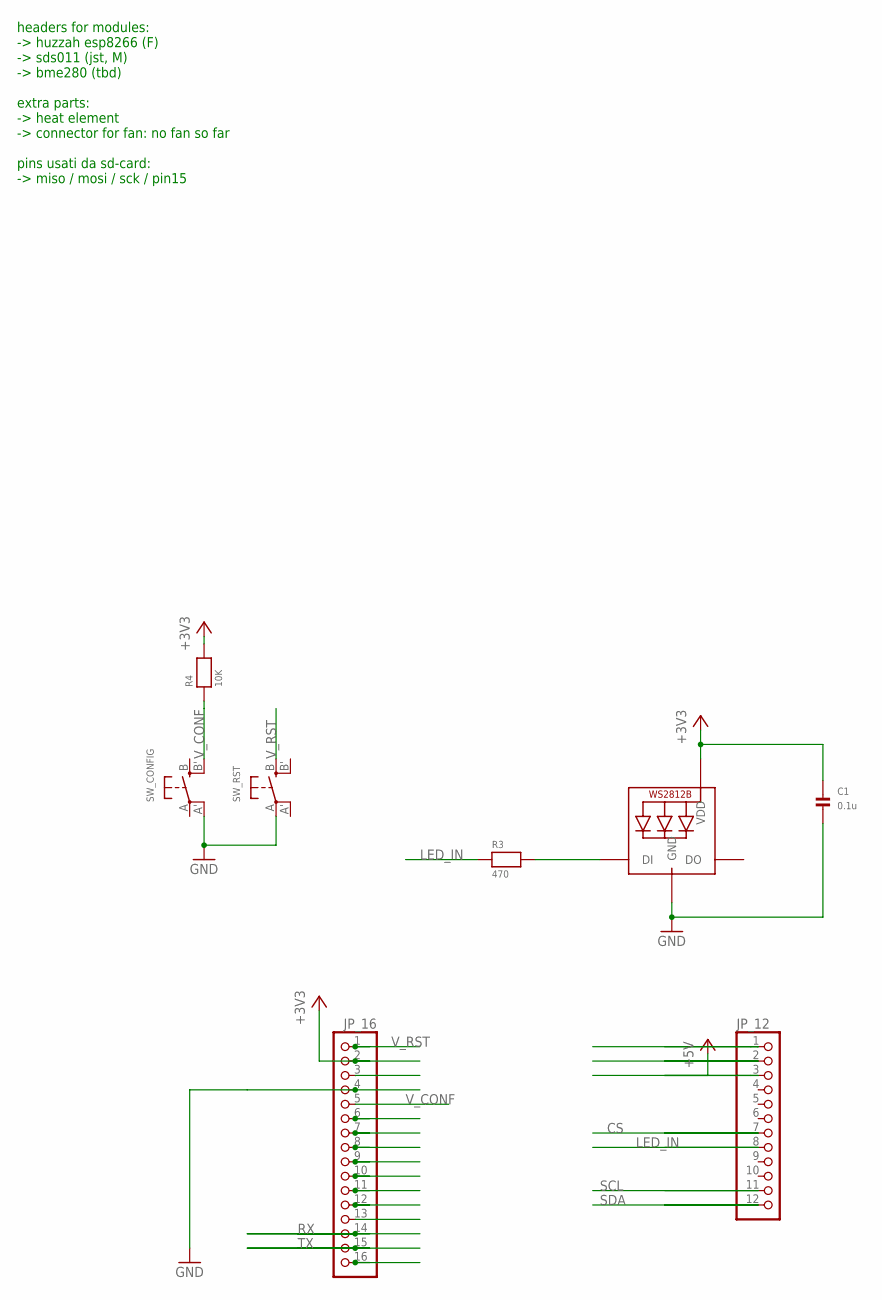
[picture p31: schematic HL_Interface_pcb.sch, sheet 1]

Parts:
C1: 0.1u; 1206
JP_12: HEADER-1X12OVAL; 1X12_OVAL
JP_16: HEADER-1X16; 1X16_OVAL
LED: WS2812B5050; WS2812B
R3: 470; 1206
R4: 10K; 1206
SW_CONFIG: SWITCH_TACT_SMT; EVQ-Q2
SW_RST: SWITCH_TACT_SMT; EVQ-Q2

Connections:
+3V3: C1.1, JP_16.2, LED.1-VDD (VDD), R4.2
+5V: JP_12.3
CS: JP_12.7
GND: C1.2, JP_16.4, LED.3-GND (GND), SW_CONFIG.A' (P1), SW_RST.A
LED_IN: JP_12.8, R3.1
unnamed: LED.4-DIN (DI), R3.2
RX: JP_16.14
SCL: JP_12.11
SDA: JP_12.12
TX: JP_16.15
V_CONF: JP_16.5, R4.1, SW_CONFIG.B' (S1)
V_RST: JP_16.1, SW_RST.B (S)

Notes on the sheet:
headers for modules: -> huzzah esp8266 (F) -> sds011 (jst, M) -> bme280 (tbd) extra parts: -> heat element -> connector for fan: no fan so far pins usati da sd-card: -> miso / mosi / sck / pin15

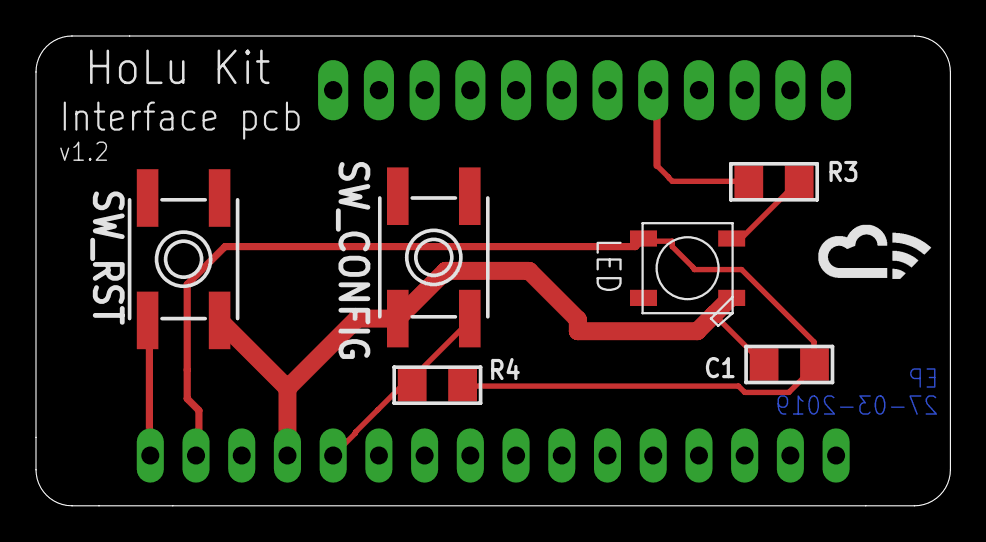
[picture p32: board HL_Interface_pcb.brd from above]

Board: 2 copper layers, 50.8 x 26.1 mm, 8 parts (0 on the bottom side), 6 nets.

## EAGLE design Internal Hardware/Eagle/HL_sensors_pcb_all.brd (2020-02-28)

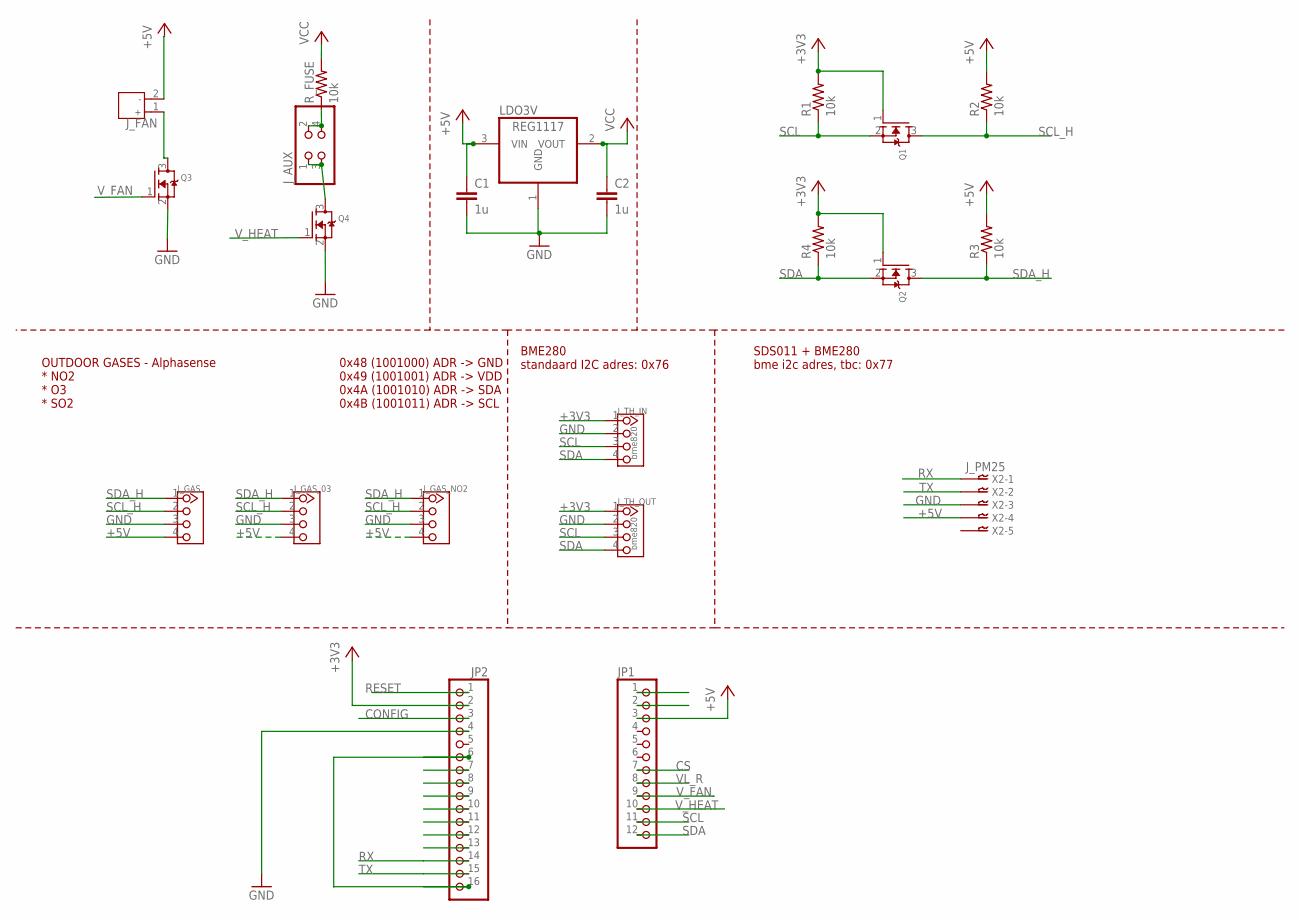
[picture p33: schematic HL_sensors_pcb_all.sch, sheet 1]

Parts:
C1, C2: 1u; C1206K
JP1: HEADER-1X12OVAL; 1X12_OVAL
JP2: HEADER-1X16; 1X16_OVAL
J_AUX: PINHD-2X2; 2X02
J_FAN: JACK-JST-2P-PW'2.0'; JST-2.0
J_GAS: TWIG-4P-2.0-2.0; 4P-2.0
J_GAS_03: TWIG-4P-2.0-2.0; 4P-2.0
J_GAS_NO2: TWIG-4P-2.0-2.0; 4P-2.0
J_TH_IN: bme820; 4P-2.0
J_TH_OUT: bme820; 4P-2.0
LDO3V: REG1117; SOT223
Q1, Q2, Q3, Q4: MOSFET-NWIDE; SOT23-WIDE
R1, R2, R3, R4: 10k; 1206
R_FUSE: 10k; 1206
X2: J_PM25; B5B-XH

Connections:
+3V3: JP2.2, J_TH_IN.1, J_TH_OUT.1, Q1.1 (G), Q2.1 (G), R1.2, R4.2
+5V: C1.1, JP1.3, J_FAN.2, J_GAS.4, J_GAS_03.4, J_GAS_NO2.4, LDO3V.3 (VIN), R2.2, R3.2, X2.P$4
CONFIG: JP2.3
CS: JP1.7
GND: C1.2, C2.2, JP2.4, J_GAS.3, J_GAS_03.3, J_GAS_NO2.3, J_TH_IN.2, J_TH_OUT.2, LDO3V.1 (GND), Q3.2 (S), Q4.2 (S), X2.P$3
unnamed: J_FAN.1, Q3.3 (D)
unnamed: J_AUX.1, J_AUX.3, Q4.3 (D)
unnamed: J_AUX.2, J_AUX.4, R_FUSE.1
unnamed: JP2.6, JP2.16
RESET: JP2.1
RX: JP2.14, X2.P$1
SCL: JP1.11, J_TH_IN.3, J_TH_OUT.3, Q1.2 (S), R1.1
SCL_H: J_GAS.2, J_GAS_03.2, J_GAS_NO2.2, Q1.3 (D), R2.1
SDA: JP1.12, J_TH_IN.4, J_TH_OUT.4, Q2.2 (S), R4.1
SDA_H: J_GAS.1, J_GAS_03.1, J_GAS_NO2.1, Q2.3 (D), R3.1
TX: JP2.15, X2.P$2
VCC: C2.1, LDO3V.2 (VOUT), R_FUSE.2
VL_R: JP1.8
V_FAN: JP1.9, Q3.1 (G)
V_HEAT: JP1.10, Q4.1 (G)

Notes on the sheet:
SDS011 + BME280 bme i2c adres, tbc: 0x77
BME280 standaard I2C adres: 0x76
OUTDOOR GASES - Alphasense * NO2 * O3 * SO2
0x48 (1001000) ADR -> GND 0x49 (1001001) ADR -> VDD 0x4A (1001010) ADR -> SDA 0x4B (1001011) ADR -> SCL

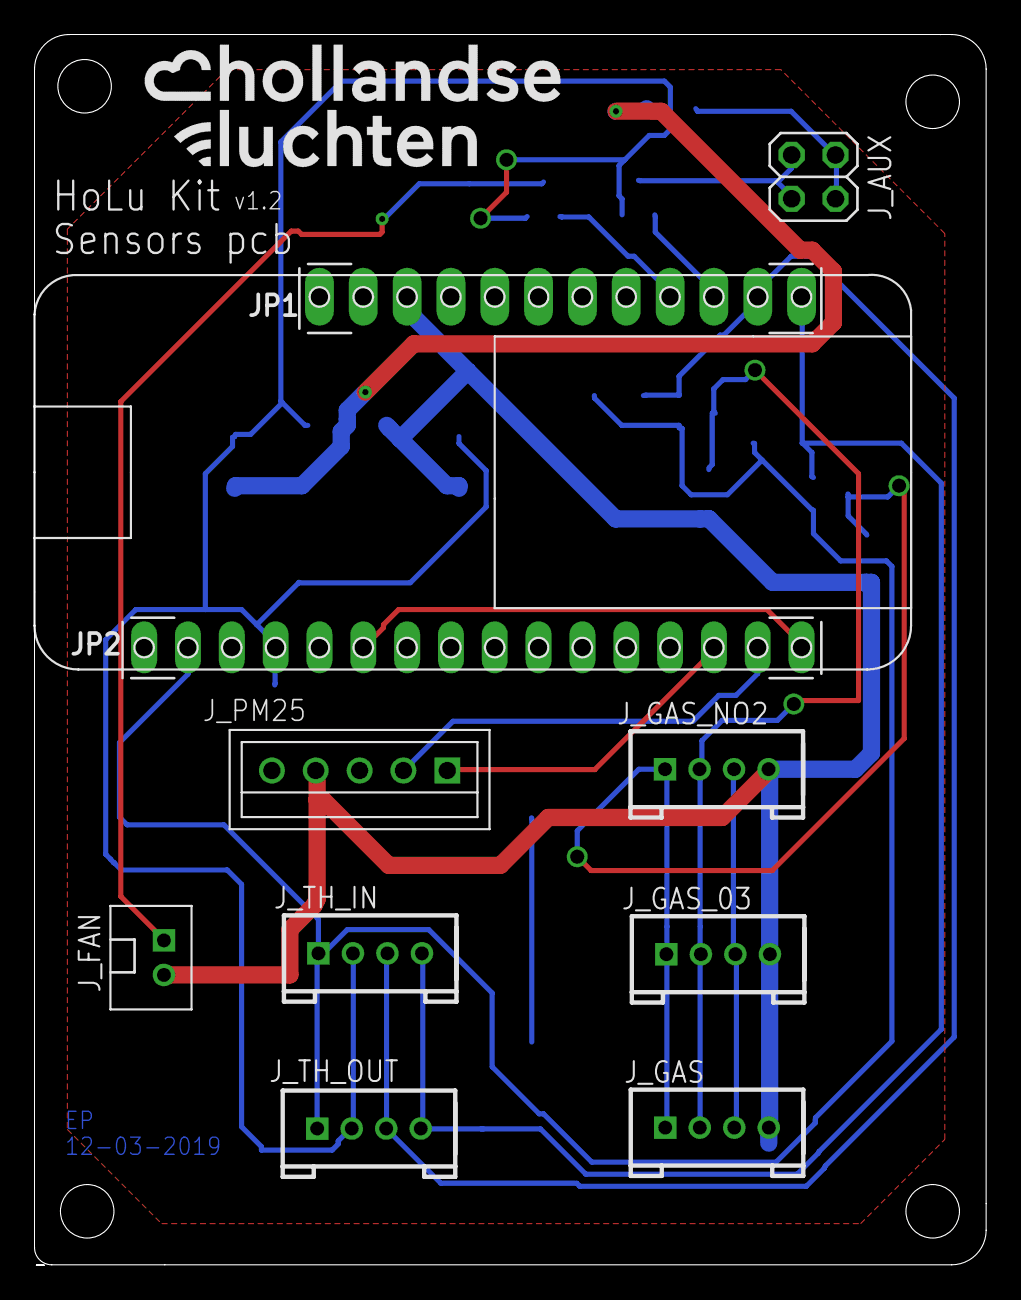
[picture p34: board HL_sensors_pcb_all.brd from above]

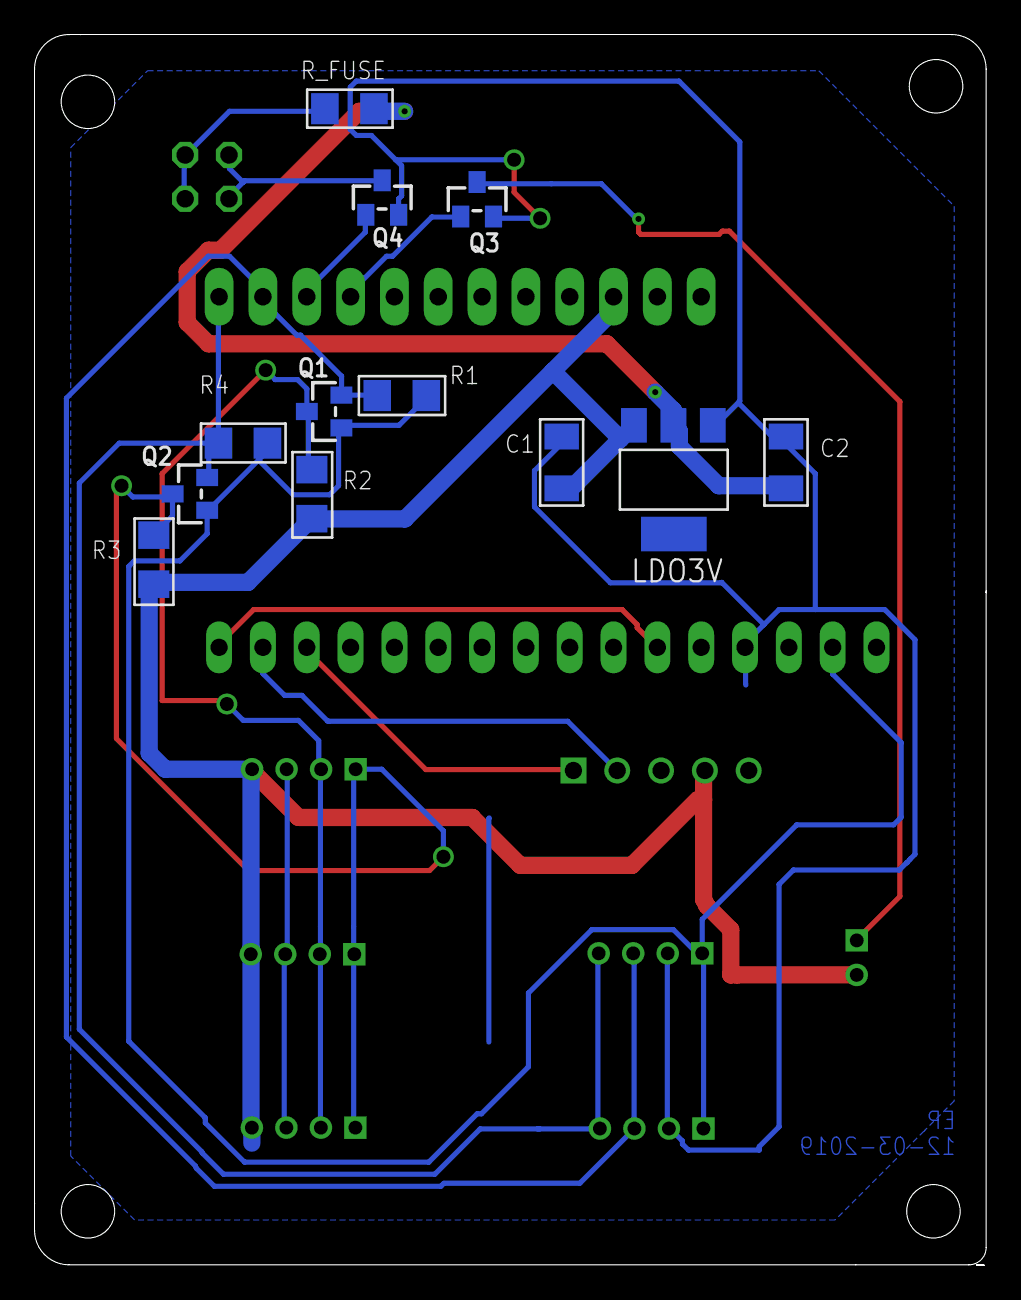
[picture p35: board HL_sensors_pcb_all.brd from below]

Board: 2 copper layers, 55.1 x 71.3 mm, 23 parts (12 on the bottom side), 16 nets.

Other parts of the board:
U$1: ADA_FEATHER_NOPADS

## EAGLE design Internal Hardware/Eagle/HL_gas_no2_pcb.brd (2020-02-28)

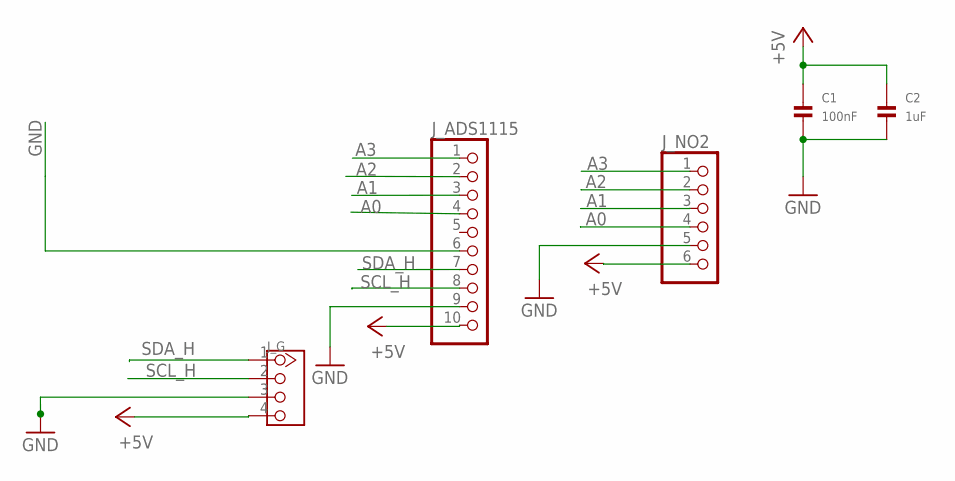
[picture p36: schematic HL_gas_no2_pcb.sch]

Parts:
C1: 100nF; 1206
C2: 1uF; 1206
J_ADS1115: HEADER-1X10; 1X10_OVAL
J_G: TWIG-4P-2.0-2.0; 4P-2.0
J_NO2: HEADER-1X6; 1X06_OVAL

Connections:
+5V: C1.1, C2.1, J_ADS1115.10, J_G.4, J_NO2.6
A0: J_ADS1115.4, J_NO2.4
A1: J_ADS1115.3, J_NO2.3
A2: J_ADS1115.2, J_NO2.2
A3: J_ADS1115.1, J_NO2.1
GND: C1.2, C2.2, J_ADS1115.6, J_ADS1115.9, J_G.3, J_NO2.5
SCL_H: J_ADS1115.8, J_G.2
SDA_H: J_ADS1115.7, J_G.1

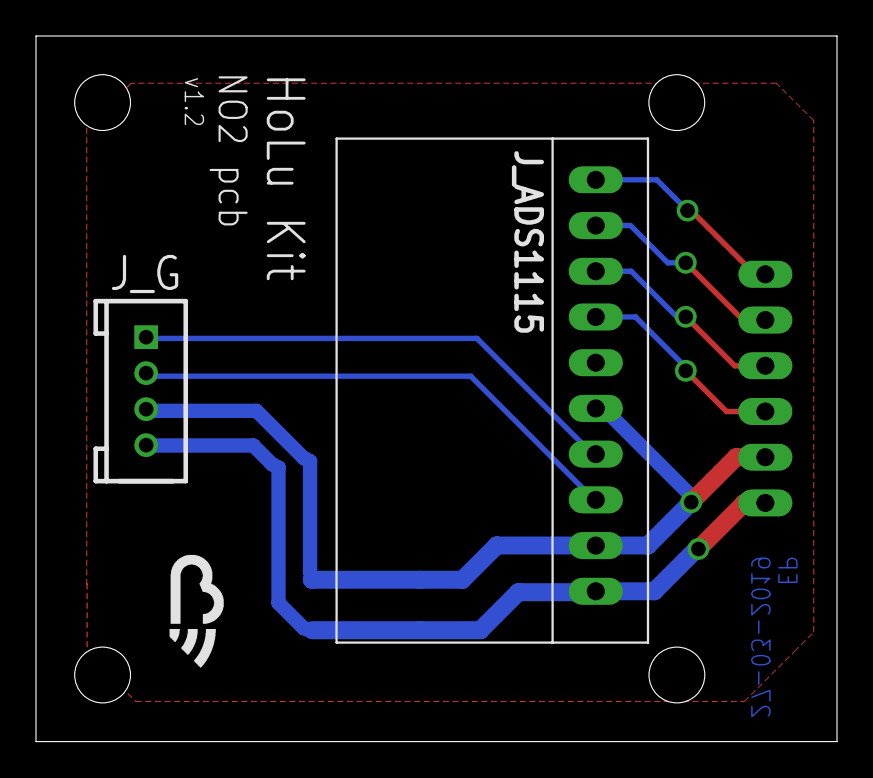
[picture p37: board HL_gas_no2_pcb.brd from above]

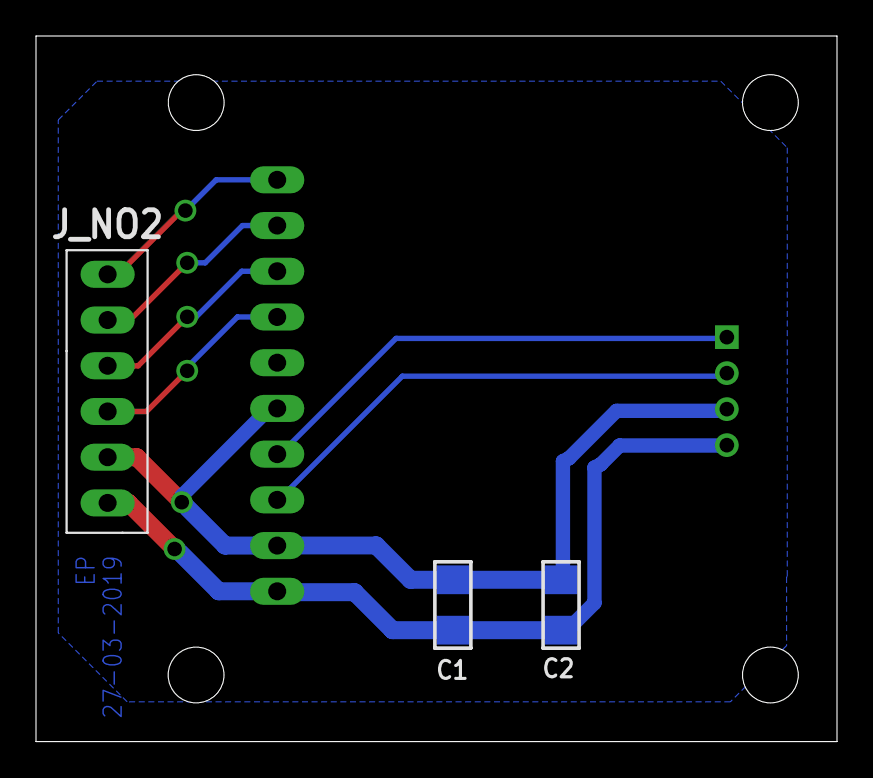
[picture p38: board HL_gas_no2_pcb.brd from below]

Board: 2 copper layers, 44.5 x 39.2 mm, 5 parts (2 on the bottom side), 8 nets.

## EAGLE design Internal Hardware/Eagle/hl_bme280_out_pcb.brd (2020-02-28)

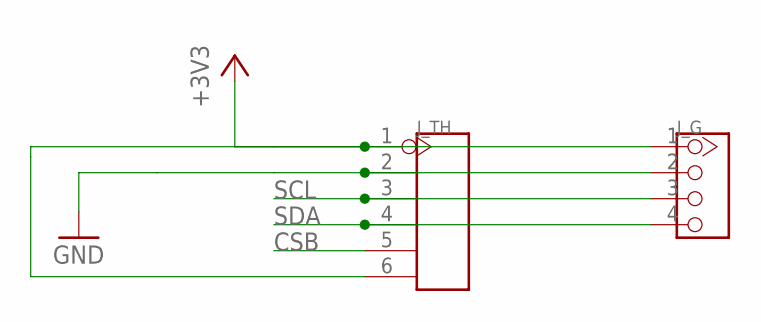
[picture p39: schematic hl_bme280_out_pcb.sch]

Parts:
J_G: TWIG-4P-2.0-2.0; 4P-2.0
J_TH: HEADER-6P-80/40MIL; 6P-2.54-80/40MIL

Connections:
+3V3: J_G.1, J_TH.1, J_TH.6
CSB: J_TH.5
GND: J_G.2, J_TH.2
SCL: J_G.3, J_TH.3
SDA: J_G.4, J_TH.4


Board: 2 copper layers, 19.4 x 25.8 mm, 3 parts (1 on the bottom side), 4 nets.

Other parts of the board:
U$1: BME280_BO_NOPADS

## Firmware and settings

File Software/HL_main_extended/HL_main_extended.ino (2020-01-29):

/*******************************************************************************
 * Emma Pareschi - June 2019
 * version 2.1
 * 
 * The MIT License (MIT)
 * Copyright 2019 Emma Pareschi
 * 
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
 * 
 *******************************************************************************/

#include <SdFat.h> //https://github.com/greiman/SdFat
#include <Wire.h> //include Wire.h library
#include "RTClib.h" //include Adafruit RTC library
#include <Wire.h> 
#include "hl_device_id.h"
#include <Adafruit_Sensor.h>
#include <Adafruit_BME280.h> //https://github.com/adafruit/Adafruit_BME280_Library/blob/master/Adafruit_BME280.h
#include <lmic.h> //https://github.com/matthijskooijman/arduino-lmic
#include <hal/hal.h>
#include <SPI.h>
#include <Adafruit_ADS1015.h> //https://github.com/adafruit/Adafruit_ADS1X15
#include <Adafruit_SleepyDog.h> //https://github.com/adafruit/Adafruit_SleepyDog

#define DEBUG 1
#define version 2.1

boolean GAS_SENSORS = true;
boolean BME_SENSOR = false;
boolean data_flag = false;
boolean flag_joined = false;
boolean flag_sdcard = false;
boolean flag_sent = false;

int timer_wd = 4000;

  static const byte DEVICE = SECRET_DEVICE;
  void os_getArtEui (u1_t* buf) { memcpy_P(buf, SECRET_APPEUI, 8);}
  void os_getDevEui (u1_t* buf) { memcpy_P(buf, SECRET_DEVEUI, 8);}
  void os_getDevKey (u1_t* buf) {  memcpy_P(buf, SECRET_APPKEY, 16);}


byte deviceID = DEVICE;
static byte mydata[26];
static osjob_t sendjob;

const unsigned TX_INTERVAL = 176;   //every three minutes

// Pin mapping Feather M0 
const lmic_pinmap lmic_pins = { 
    .nss = 8,
    .rxtx = LMIC_UNUSED_PIN,
    .rst = 4,
    .dio = {3, 15, LMIC_UNUSED_PIN},  
};

const int cs_lora = 8;

//=======================================================
// *** SDS011 ***
unsigned int Pm25 = 0;
unsigned int Pm10 = 0;
int  Status_sds = -1;
int LastError_sds = 0;
float p10 = 0.0, p25 = 0.0;

int error;
int count = 0;
int cnt = 0;
int ecnt = 0;
int ecnt_s = 0;

float s25 = 0.0;
float s10 = 0.0;

float pm25 = 0.0;
float pm10 = 0.0;


//---------------//---------------//----------------//
const byte sds_period = 180; //measuring period of sds in seconds
const byte start_measure = 25;


//=======================================================
// *** SD CARD *** // 
int chipSelect = 10; //chip select pin for the MicroSD Card Adapter
File file; // file object that is used to read and write data
String header;
char file_name[16]; // make it long enough to hold your longest file name, plus a null terminator
boolean sdcard_ok = false;
SdFat SD;

//=======================================================
// ***RTC*** //
RTC_PCF8523 rtc;

int timestamp[30];

//=======================================================
// *** BME280s *** //
Adafruit_BME280 bme;

     float tempIN = 0;
     float tempIN_tot = 0;
     float tempIN_avg = 0;

     float humIN = 0;
     float humIN_tot = 0;
     float humIN_avg = 0;
     float last_humIN_avg = 0;

int bme_counter = 0;
int counter = 0;


//=======================================================
// *** OUTPUTs *** //
#include <Adafruit_NeoPixel.h>

#define LEDpin 9

Adafruit_NeoPixel pixel = Adafruit_NeoPixel(1, LEDpin, NEO_RGB + NEO_KHZ800);

uint32_t red = pixel.Color(0, 0, 0);
uint32_t green = pixel.Color(0, 0, 0);
uint32_t blue = pixel.Color(0, 0, 0);
uint32_t off = pixel.Color(0, 0, 0);
uint32_t on = pixel.Color(0,0 ,0);

//=======================================================
// *** ADC *** //

 Adafruit_ADS1115 ads_no2;  //no2
 Adafruit_ADS1115 ads_o3(0x4A); //o3

int o3_op1 = 0;
int o3_op2 = 0;
int no2_op1 = 0;
int no2_op2 = 0;

int o3_op1_tot = 0;
int o3_op2_tot = 0;
int no2_op1_tot = 0;
int no2_op2_tot = 0;

int16_t o3_op1_avg = 0;
int16_t o3_op2_avg = 0;
int16_t no2_op1_avg = 0;
int16_t no2_op2_avg = 0;

int8_t no2[4];

//=======================================================
// *** Function for LORA *** //
void onEvent (ev_t ev) {
    Serial.print(os_getTime());
    Serial.print(": ");
    switch(ev) {
        case EV_SCAN_TIMEOUT:
            Serial.println(F("EV_SCAN_TIMEOUT"));
            break;
        case EV_BEACON_FOUND:
            Serial.println(F("EV_BEACON_FOUND"));
            break;
        case EV_BEACON_MISSED:
            Serial.println(F("EV_BEACON_MISSED"));
            break;
        case EV_BEACON_TRACKED:
            Serial.println(F("EV_BEACON_TRACKED"));
            break;
        case EV_JOINING:
            Serial.println(F("EV_JOINING"));
            flag_joined = false;
            blinks(1, 200, off, red);
            break;
        case EV_JOINED:
            Serial.println(F("EV_JOINED"));
            flag_joined = true;
            blinks(1, 200, off, green);
            Watchdog.enable(timer_wd);
            break;
        case EV_RFU1:
            Serial.println(F("EV_RFU1"));
            break;
        case EV_JOIN_FAILED:
            Serial.println(F("EV_JOIN_FAILED"));
            //blinks(1, 200, off, red);
            break;
        case EV_REJOIN_FAILED:
            Serial.println(F("EV_REJOIN_FAILED"));
            //blinks(1, 200, off, red);           
            break;
        case EV_TXCOMPLETE:
            Serial.println(F("EV_TXCOMPLETE (includes waiting for RX windows)"));
            if(flag_joined == true) {
                blinks(2, 300, off, green);
                pixel.setPixelColor(0, green);
                pixel.show();
                delay(1);
            }
            if (LMIC.txrxFlags & TXRX_ACK)
              Serial.println(F("Received ack"));
            if (LMIC.dataLen) {
              Serial.println(F("Received "));
              Serial.println(LMIC.dataLen);
              Serial.println(F(" bytes of payload"));
            }
            // Schedule next transmission
            os_setTimedCallback(&sendjob, os_getTime()+sec2osticks(TX_INTERVAL), do_send);
            break;
        case EV_LOST_TSYNC:
            Serial.println(F("EV_LOST_TSYNC"));
            break;
        case EV_RESET:
            Serial.println(F("EV_RESET"));
            break;
        case EV_RXCOMPLETE:
            // data received in ping slot
            Serial.println(F("EV_RXCOMPLETE"));
            break;
        case EV_LINK_DEAD:
            Serial.println(F("EV_LINK_DEAD"));
            break;
        case EV_LINK_ALIVE:
            Serial.println(F("EV_LINK_ALIVE"));
            break;
         default:
            Serial.println(F("Unknown event"));
            break;
    }
}

void do_send(osjob_t* j){
  
    // Check if there is not a current TX/RX job running
    if (LMIC.opmode & OP_TXRXPEND) {
        Serial.println(F("OP_TXRXPEND, not sending"));
    } else {
        // Prepare upstream data transmission at the next possible time.
        mydata[0] = deviceID;
        mydata[1] = timestamp[0] >> 8;      //YY_1
        mydata[2] = timestamp[0] & 0xFF;    //YY_2
        mydata[3] = timestamp[1];           //MM
        mydata[4] = timestamp[2];           //DD   
        mydata[5] = timestamp[3];           //h   
        mydata[6] = timestamp[4];           //m
        mydata[7] = timestamp[5];           //s     

        int pm25_aux = (pm25 * 100);        
        mydata[8] = pm25_aux >> 8;           //pm25 1
        mydata[9] = pm25_aux & 0xFF;         //pm25 2

        int pm10_aux = (pm10 * 100);        
        mydata[10] = pm10_aux >> 8;           //pm25 1
        mydata[11] = pm10_aux & 0xFF;         //pm25 2

        int tempIN_aux = round((tempIN_avg+100) * 100);
        mydata[12] = tempIN_aux >> 8;            //tempIN 1
        mydata[13] = tempIN_aux  & 0xFF;         //tempIN 2
        
        int humIN_aux = (humIN_avg * 100);
        mydata[14] = humIN_aux >> 8;              //humIN 1
        mydata[15] = humIN_aux  & 0xFF;           //humIN 2

    if (GAS_SENSORS == true){
        mydata[16] = no2_op1_avg >> 8;
        mydata[17] = no2_op1_avg & 0xFF;
        mydata[18] = no2_op2_avg >> 8;
        mydata[19] = no2_op2_avg & 0xFF;

        mydata[20] = o3_op1_avg >> 8;
        mydata[21] = o3_op1_avg & 0xFF;
        mydata[22] = o3_op2_avg >> 8;
        mydata[23] = o3_op2_avg & 0xFF;
    }
        LMIC_setTxData2(1, mydata, sizeof(mydata)-1, 0);
        
        Serial.println(F("Packet queued"));
    }
}

//=======================================================
// SETUP
void setup () {

  pixel.begin();
  delay(10);
  pixel.setBrightness(100);
  pixel.setPixelColor(0, on);
  pixel.show();
  delay(100);
  
  Serial.begin(9600);
  Serial1.begin(9600);
  delay(5000);

  Serial.println(F("Starting"));
  Serial.println(F("HoLu kit v1.2"));
  Serial.print("code version: "); Serial.println(version);
  Serial.print("device ID: "); Serial.println(DEVICE);
  Serial.println("Connected sensors:");
  Serial.println("-> sds011: pm25, pm10");
  Serial.println("-> bme280: temp, hum");
  
  if(GAS_SENSORS == true){
      Serial.println("-> NO2 alphasense");
      Serial.println("-> O3 alphasense");
  }

      
  // ** INITIALIZE CARD ** //
  
  pinMode(cs_lora, OUTPUT);
  digitalWrite(cs_lora, HIGH);
  
  pinMode(chipSelect, OUTPUT); // chip select pin must be set to OUTPUT mode
  digitalWrite(chipSelect, HIGH);
  
  sdcard_ok = SD.begin(chipSelect);
  delay(1);
   
  if(sdcard_ok == false) { // Initialize SD card
    Serial.println("");  
    Serial.println("***CARD********************************************");
    Serial.println("Could not initialize SD card."); // if return value is false, something went wrong.
    blinks(2, 200, off, red);
    flag_sdcard = false;
  //  return;    
  } else {
    Serial.println("");  
    Serial.println("***CARD********************************************");
    Serial.println("card initialized.");   
    flag_sdcard = true;     //set flag for sd card as true
    blinks(2, 200, off, blue);
  }

  int n = 0;
  snprintf(file_name, sizeof(file_name), "data%03d.txt", n); // includes a three-digit sequence number in the file name

 // if (flag_sdcard == true){
  while(SD.exists(file_name)) {
    n++;
    snprintf(file_name, sizeof(file_name), "data%03d.txt", n);
  }
  Serial.print("file name: "); Serial.println(file_name);

  delay(1000);

  // ** Write Log File Header 
  file = SD.open(file_name, FILE_WRITE); // open "file.txt" to write data
  if (file)
  {
     //file.println(" "); //Just a leading blank line, in case there was previous data
    if(GAS_SENSORS == true){
      header = "DeviceID, Timestamp, PM2.5, PM10, Temp (C), Humidity (%), NO2 op1, NO2 op2, O3 op1, O3 op2";
    } else {
      header = "DeviceID, Timestamp, PM2.5, PM10, Temp (C), Humidity (%)";
    }
    file.println(header);
    file.close();
    Serial.print("header: ");
    Serial.println(header);
    Serial.println();
    blinks(2, 200, off, blue);    
  }
  else
  {
    Serial.println("Couldn't open log file");
    blinks(2, 200, off, red);
  }
 // }

 digitalWrite(cs_lora, LOW);

  // ** INITIALIZE RTC ** //
  
   if (! rtc.begin()) {
   Serial.println("Couldn't find RTC");
   while (1);
  } else {
   Serial.println("RTC ready: ");
  }

  if (! rtc.initialized()) {
    Serial.println("RTC is NOT running!");
    // following line sets the RTC to the date & time this sketch was compiled
     rtc.adjust(DateTime(F(__DATE__), F(__TIME__)));
    // This line sets the RTC with an explicit date & time, for example to set
    // January 21, 2014 at 3am you would call:
    // rtc.adjust(DateTime(2014, 1, 21, 3, 0, 0));
  }

        DateTime now = rtc.now();
        Serial.print(now.year()); Serial.print("/");
        Serial.print(now.month()); Serial.print("/");
        Serial.print(now.day()); Serial.print(" - ");

        Serial.print(now.hour()-1); Serial.print(":");
        Serial.print(now.minute()); Serial.print(":");
        Serial.println(now.second());
        //Serial.println("********************************************************");
        Serial.println();

   bool status;    
   status = bme.begin(); 
   delay(1000); 
   
  if (!status) { 
    Serial.println("Could not find the BME280 IN sensor, check wiring!"); 
    BME_SENSOR = false;
   } else {
    Serial.println("***BME280******************************************");
    Serial.println("bme ready. ");
    BME_SENSOR = true;
    delay(5);
    Serial.print("Temp: "); Serial.println(bme.readTemperature()); 
    Serial.print("Hum: "); Serial.println(bme.readHumidity());
    Serial.println();
   }

   ads_no2.begin();
   ads_o3.begin();
   delay(200);
   data_ads();
   delay(10);

    Serial.println("***ALPHA NO2******************************************");
    Serial.println("no2 sensor ready? ");   
    delay(5);
    Serial.print("no2a: "); Serial.println(no2_op1); 
    Serial.print("no2b: "); Serial.println(no2_op2);
    Serial.println();    

    Serial.println("***ALPHA O3******************************************");
    Serial.println("o3 sensor ready? ");   
    delay(5);
    Serial.print("o3a: "); Serial.println(o3_op1); 
    Serial.print("o3b: "); Serial.println(o3_op2);
    Serial.println();    

   

// ** LORA ** //
  #ifdef VCC_ENABLE
    // For Pinoccio Scout boards
    pinMode(VCC_ENABLE, OUTPUT);
    digitalWrite(VCC_ENABLE, HIGH);
    delay(1000);
  #endif

  // LMIC init
    os_init();
    
  // Reset the MAC state. Session and pending data transfers will be discarded.
    LMIC_reset();
    
  // Start job
    do_send(&sendjob);


}


void loop() {
  
   Watchdog.reset();

   delay(1);
   os_runloop_once();
    
    ProcessSerialData();

    float  x6 = LastError_sds;

    if (p25 > -1.0 && p10 > -1.0) {
      Serial.print("PM2.5 = "); Serial.println(p25);
      Serial.print("PM10 = "); Serial.println(p10);
       cnt += 1;
       ecnt =0;
       ecnt_s =0;
       data_flag = true;
    }
    else {
      x6 = (float) LastError_sds;
      //Serial.print("\tERROR= ");
      //Serial.print(LastError_sds);
      //Serial.print("\t ");
      ecnt++;

      data_flag = false;
    }

  // set to zero millisecond count
  if (ecnt > 999){
    ecnt = 0;
   Watchdog.reset();
    ecnt_s++;

  Serial.print("\tECOUNT SEC= "); Serial.println(ecnt_s); 
       
    // measure temp/hum
    if ( ecnt_s >= start_measure && ecnt_s <= sds_period){
        bme_counter++;
             
    if(BME_SENSOR == true){
     data_bme();
     tempIN_tot += tempIN;
     humIN_tot += humIN;
     } else {
       tempIN_tot = 0;
       humIN_tot = 0;     
     }

  if(GAS_SENSORS == true){
     data_ads();
      o3_op1_tot += o3_op1;
      o3_op2_tot += o3_op2;
      no2_op1_tot += no2_op1;
      no2_op2_tot += no2_op2;   }
    }      
  }
  
  if (ecnt_s > sds_period){
    ecnt_s = 0;

    tempIN_avg = 0;
    tempIN_tot = 0;
    
    humIN_avg = 0;
    humIN_tot = 0;

    no2_op1_avg = 0;
    no2_op2_avg = 0;
    o3_op1_avg = 0;
    o3_op2_avg = 0;
  }

  // if the data from sds are valid:  
  // - make the avarage of the temp/hum values
  // - save the data on sdcard
  
  if (data_flag == true){ 

        pm25 = p25;
        pm10 = p10;   
               
        data_time();         //get the timestamp
        
        delay(1);
        
        tempIN_avg = tempIN_tot/bme_counter;
        humIN_avg = humIN_tot/bme_counter;

        //FILTER TEMP
        int temp_aux = (tempIN_avg * 100);
        int temp_aux_1 = temp_aux >> 8;            //tempIN 1
        int temp_aux_2 = temp_aux  & 0xFF;         //tempIN 2
        
        if (temp_aux_1 > 254 && temp_aux_2 > 254){  
          data_bme();
          tempIN_avg = tempIN;
          humIN_avg = humIN;        
        }

        //FILTER HUM - under test
        if(humIN_avg > 100 || humIN_avg < 0){
            humIN_avg = last_humIN_avg;
        } else {
            last_humIN_avg = humIN_avg;
        }

        
     if(GAS_SENSORS == true){
        o3_op1_avg = o3_op1_tot/bme_counter;
        o3_op2_avg = o3_op2_tot/bme_counter;
        no2_op1_avg = no2_op1_tot/bme_counter;
        no2_op2_avg = no2_op2_tot/bme_counter;
     }

        Serial.print("Day: "); 
        for (int i = 0 ; i < 3; i++){
          Serial.print(timestamp[i]);Serial.print(" ");
        } Serial.println("");
        Serial.print("Time: ");
        for (int i = 3 ; i < 6; i++){
          Serial.print(timestamp[i]);Serial.print(" ");
        } Serial.println(""); 
        Serial.print("TempIN_avg: "); Serial.print(tempIN_avg); Serial.print("\t TempIN_tot: "); Serial.println(tempIN_tot); 
        Serial.print("HumIN_avg: "); Serial.print(humIN_avg); Serial.print("\t HumIN_tot: "); Serial.println(humIN_tot); 
      if(GAS_SENSORS == true){        
        Serial.print("o3_op1_avg: "); Serial.print(o3_op1_avg); Serial.print("\t o3_op1_tot: "); Serial.println(o3_op1_tot);
        Serial.print("o3_op2_avg: "); Serial.print(o3_op2_avg); Serial.print("\t o3_op2_tot: "); Serial.println(o3_op2_tot);  
        Serial.print("no2_op1_avg: "); Serial.print(no2_op1_avg); Serial.print("\t no2_op1_tot: "); Serial.println(no2_op1_tot);
        Serial.print("no2_op2_avg: "); Serial.print(no2_op2_avg); Serial.print("\t no2_op2_tot: "); Serial.println(no2_op2_tot);   
      } 
        Serial.print("bme counter: "); Serial.println(bme_counter);
        bme_counter = 0;
        tempIN_tot = 0;
        humIN_tot = 0;
        o3_op1_tot = 0;
        o3_op2_tot = 0;
        no2_op1_tot = 0;
        no2_op2_tot = 0;
             
        delay(10);

        if (flag_sdcard = true){
          data_log();
          delay(1);
        }       
        data_flag = false;
  
      } else {
        data_flag = false;
      }
      

}


// FUNCTION for SDS
void ProcessSerialData()
{

  uint8_t mData = 0;
  uint8_t i = 0;
  uint8_t mPkt[10] = {0};
  uint8_t mCheck = 0;

  Status_sds = -1;  // Default: no data availabe ...
  p10 = -1.0;
  p25 = -1.0;

  while (Serial1.available() > 0)
  {
    // from www.inovafitness.com
    // packet format: AA C0 PM25_Low PM25_High PM10_Low PM10_High 0 0 CRC AB

    Status_sds = 0; // There is data!

    mData = Serial1.read();
    delay(10);//wait until packet is received

    if (mData == 0xAA) // Head1 ok?
    {
      mPkt[0] =  mData;
      mData = Serial1.read();

      if (mData == 0xc0) // Head2 ok?
      {
        mPkt[1] =  mData;
        mCheck = 0;
        for (i = 0; i < 6; i++) // Get the content of the package!
        {
          mPkt[i + 2] = Serial1.read();
          delay(2);
          mCheck += mPkt[i + 2];
        }

        mPkt[8] = Serial1.read();
        delay(5);

        mPkt[9] = Serial1.read();
        if (mPkt[9] != 0xAB) {
          Serial.print("\nmData[9] != 0xAB,  but ");
          Serial.println(mPkt[9]);
          Status_sds = 4; LastError_sds = Status_sds; ecnt++;
        }

        if (mCheck == mPkt[8]) // Check CRC
        {
          Serial1.flush();
          //Serial.write(mPkt,10);

          Pm25 = (uint16_t)mPkt[2] | (uint16_t)(mPkt[3] << 8);
          Pm10 = (uint16_t)mPkt[4] | (uint16_t)(mPkt[5] << 8);

          if (Pm25 > 9999)
            Pm25 = 9999;
          if (Pm10 > 9999)
            Pm10 = 9999;

          p25 = Pm25 / 10.0;
          p10 = Pm10 / 10.0;

          while (Serial1.available() > 0) {  // Zap buffer ...
            mData = Serial1.read();
          }

          return;  // We now have one good packet :-))

        } // CRC ??
        else {
          Serial.print("\nCRC != OK,  ");
          Serial.print(mCheck);
          Serial.print("  !=  ");
          Serial.println(mPkt[8]);
          Status_sds = 3; LastError_sds = Status_sds; ecnt++;
        }

      } // Head2 ??
      else {
        Serial.print("\nmData != 0xc0,  but ");
        Serial.println(mData);
        Status_sds = 2; LastError_sds = Status_sds; ecnt++;
      }

    } // Head1 ??
    else {
      Serial.print("\nmData != 0xAA,  but ");
      Serial.println(mData);
      Status_sds = 1; LastError_sds = Status_sds; ecnt++;
    }
  }
}

void data_bme(){ 
  // ** get temp/hum
//  tempIN = -22.90;
//  humIN = 5.55;   

  tempIN = bme.readTemperature();
  humIN = bme.readHumidity();   
  delay(1);   
}


void data_ads(){ 
  
   o3_op1 = ads_o3.readADC_Differential_0_1();
   delay(1);
   o3_op2 = ads_o3.readADC_Differential_2_3();
   delay(1);
  
   no2_op1 = ads_no2.readADC_Differential_0_1();
   delay(1);
   no2_op2 = ads_no2.readADC_Differential_2_3();
   delay(1);
}

void data_time(){

  // ** get the timestamp
        DateTime now = rtc.now();
        timestamp[0] = now.year();
        timestamp[1] = now.month();
        timestamp[2] = now.day();

        timestamp[3] = now.hour()-1;
        timestamp[4] = now.minute();
        timestamp[5] = now.second();

        if(timestamp[3] == -2) timestamp[3] = 22;
        if(timestamp[3] == -1) timestamp[3] = 23;
}


//function to blink the led
void blinks(byte NUMBLINKS, int blink_delay, uint32_t color1, uint32_t color2){
      for (int i = 0; i<NUMBLINKS+1; i++){
      pixel.setPixelColor(0, color1);
      pixel.show();
      delay(blink_delay);
      pixel.setPixelColor(0, color2);
      pixel.show();
      delay(blink_delay);
      }
}
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

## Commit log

2020-01-29 extended sketch - 3d model
    [HoLu kit Bottom case.STEP, HoLu kit Top case.STEP]
2020-02-28 update hardware and BOM
    [BOM_HoLu_kit.xlsx, HL_Interface_pcb.brd, HL_Interface_pcb.sch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]

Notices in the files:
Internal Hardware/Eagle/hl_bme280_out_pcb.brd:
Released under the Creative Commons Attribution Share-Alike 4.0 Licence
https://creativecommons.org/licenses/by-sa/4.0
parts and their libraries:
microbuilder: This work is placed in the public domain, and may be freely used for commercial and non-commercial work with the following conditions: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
